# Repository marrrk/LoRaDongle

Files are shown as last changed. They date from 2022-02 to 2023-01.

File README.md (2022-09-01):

# LoRaDongle

LoRaDongle is a custom PCB that merges Risc-V with LoRa in a USB Dongle form factor. This repository contains all the project files required to build, utilise and modify the project. Documentation can be read from the site: [https://marrrk.github.io/LoRaDongle/](https://marrrk.github.io/LoRaDongle/)

## Cloning the repository

```bash
git clone --recurse-submodules https://github.com/marrrk/LoRaDongle.git
```

## Directory Structure

- PCB/ -  Contains the Kicad project files, schematics, gerbers, BOM and other PCB related files
- SOC/ - The python scripts that generate, build and load the Risc-V SoC onto the PCB
- firmware/ -  SUpporting firmware that runs on the SoC
- docs/ - Source files for the documentation website

**License** Licensed under [CERN-OHL-P v2](https://cern-ohl.web.cern.ch/) permissive variant or later.



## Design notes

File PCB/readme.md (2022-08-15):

# Overview
In order to open the Kicad project, open kicad and open the project file `LoRaDongle_iCE40.kicad_pro`. The schematic has been implemented with hierarchal sheets which allows the different submodules to be their own separate schematic. There are five total schematics for each module;
1. LoRaDongle_ice40.kicad_sch
2. power_management.kicad_sch
3. USB_Interface.kicad_sch
4. ice40up5k_sircuit.kicad_sch
5. sx1261_circuitry.kicad_sch

The other files and directories of relevance are:
- libraries/ - kicad symbols and footprints of specific components used
- manufacturing/  - gerbers, assembly files and images for manufacturing
- pdf_schematic/ - pdfs of the schematics of all versions
- silksceen/ - images that are converted into silkscreen footprints

# Contents of the Schematics
## LoRaDongle_ice40
The root schematic that is at the top of the heirarchy. Contains the connecting signals between various subsystems and other components such as the USB connector.

## power_management.kicad_sch
Contains the board's regulator. Steps down 5V to 3.3V and 1.2V.

## USB_Interface.kicad_sch
Houses the FTDI FT2232HL IC that converts the USB protocol into SPI for the FPGA configuration and UART for communicating with the SoC.

## ice40up5k_circuit.kicad_sch
This schematic holds the FPGA banks and related circuitry. This includes the SPI Flash, the oscillator, gas sensor and a header of all unused pins.

## sx1261_circuitry.kicad_sch
This is the RF section of the schematic. It contains the LoRa chip used (SX1261) and the supporting circuitry.

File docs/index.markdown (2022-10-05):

---
# Feel free to add content and custom Front Matter to this file.
# To modify the layout, see https://jekyllrb.com/docs/themes/#overriding-theme-defaults

layout: home
title: Home
nav_order: 1
---
## Introduction

LoRaDongle is a project that aims to merge the Open Source ISA Risc-V with the wireless modulation protocol LoRa.

Currently, the second prototype is in development in which various different tools and systems are brought together to build the project.
The project is executed on a custom PCB that is populated with a Low Power Lattice FPGA - the iCE40UP5k that houses a softcore SoC.  On the same board, a SX1261 LoRa transeiver is populated and configured to transmit at 868MHz.

The two prototypes and therefore design evolution are pictured below.
<div>
    LoRaDongle Versions
</div>

**License** Licensed under [CERN-OHL-P v2](https://cern-ohl.web.cern.ch/) or later.

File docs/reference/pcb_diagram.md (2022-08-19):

---
title: PCB
layout: page
parent: Reference Guide
nav_order: 2
---

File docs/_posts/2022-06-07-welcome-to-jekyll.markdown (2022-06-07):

---
layout: post
title:  "Welcome to Jekyll!"
date:   2022-06-07 11:42:06 +0200
categories: jekyll update
---
You’ll find this post in your `_posts` directory. Go ahead and edit it and re-build the site to see your changes. You can rebuild the site in many different ways, but the most common way is to run `jekyll serve`, which launches a web server and auto-regenerates your site when a file is updated.

Jekyll requires blog post files to be named according to the following format:

`YEAR-MONTH-DAY-title.MARKUP`

Where `YEAR` is a four-digit number, `MONTH` and `DAY` are both two-digit numbers, and `MARKUP` is the file extension representing the format used in the file. After that, include the necessary front matter. Take a look at the source for this post to get an idea about how it works.

Jekyll also offers powerful support for code snippets:

{% highlight ruby %}
def print_hi(name)
  puts "Hi, #{name}"
end
print_hi('Tom')
#=> prints 'Hi, Tom' to STDOUT.
{% endhighlight %}

Check out the [Jekyll docs][jekyll-docs] for more info on how to get the most out of Jekyll. File all bugs/feature requests at [Jekyll’s GitHub repo][jekyll-gh]. If you have questions, you can ask them on [Jekyll Talk][jekyll-talk].

[jekyll-docs]: https://jekyllrb.com/docs/home
[jekyll-gh]:   https://github.com/jekyll/jekyll
[jekyll-talk]: https://talk.jekyllrb.com/

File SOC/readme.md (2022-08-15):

# Introduction
This directory houses the SOC files. There exist the platform `Platform/LoRaDongle.py` and the target `LoRaDongle.py`. The platform describes the boards physical constraints while the target creates the SoC.

# Pre-requisites
The following tools need to be installed in order to succesfully generate and flash the SoC:
- LiteX
- Project IceStorm

# Building the SoC
Simply run the target script to generate the SoC.
```
$ python LoRaDongle.py --build
```

The script uses a vexriscv-lite as the default risc-v core. To change to the required core (Serv is the main core used in the project) run the following command:
```
$ python LoRaDongle.py --cpu-type serv --build
```

# Flashing the SoC
The same command can be run with the argument `--flash` to load the SoC onto the board.
```
$ python LoRaDongle.py --cpu-type serv --build --flash
```

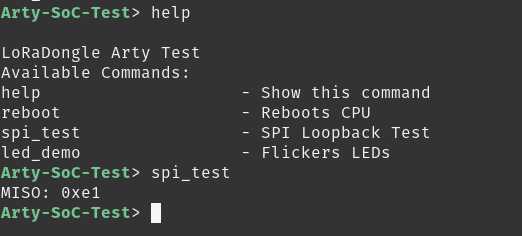
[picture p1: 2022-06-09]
docs/assets/images/soc_console_example.png

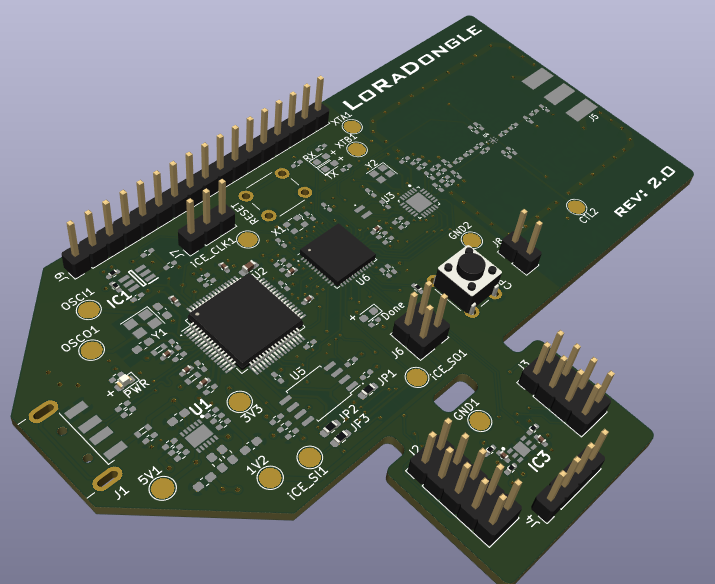
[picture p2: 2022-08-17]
docs/assets/images/LoRaDongle_V2.png

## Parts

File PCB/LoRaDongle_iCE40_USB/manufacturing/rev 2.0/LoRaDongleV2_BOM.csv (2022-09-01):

Item | Qty | Reference(s) | Value | Footprint | Description | Manufacturer | Manufacturer Part Number | Package | Type
1 | 12 | C1, C8, C9, C10, C12, C13, C16, C18, C19, C20, C21, C22 | 0.1uF | Capacitor_SMD:C_0402_1005Metric_Pad0.74x0.62mm_HandSolder | CAP CER 0.1UF 16V X7R 0402 | Murata Electronics | GCM155R71C104KA55J | 402 | SMD
2 | 3 | C2, C4, C6 | 10uF | Capacitor_SMD:C_0603_1608Metric_Pad1.08x0.95mm_HandSolder | CAP CER 10UF 6.3V X5R 0603 | Murata Electronics | GRM188R60J106ME47D | 603 | SMD
3 | 3 | C3, C5, C47 | 22pF | Capacitor_SMD:C_0402_1005Metric_Pad0.74x0.62mm_HandSolder | CAP CER 22PF 50V C0G/NP0 0402 | Murata Electronics | GRM1555C1H220FA01D | 402 | SMD
4 | 3 | C7, C11, C17 | 4.7uF | Capacitor_SMD:C_0402_1005Metric_Pad0.74x0.62mm_HandSolder | CAP CER 4.7UF 6.3V X6S 0402 | Murata Electronics | GRM155C80J475MEAAD | 402 | SMD
5 | 2 | C14, C15 | 27pF | Capacitor_SMD:C_0603_1608Metric_Pad1.08x0.95mm_HandSolder | CAP CER 27PF 50V C0G/NP0 0603 | Murata Electronics | GRM1885C1H270JA01D | 603 | SMD
6 | 11 | C23, C24, C25, C26, C27, C29, C30, C31, C32, C33, C57 | 100nF | Capacitor_SMD:C_0402_1005Metric_Pad0.74x0.62mm_HandSolder | CAP CER 0.1UF 16V X7R 0402 | Murata Electronics | GRM155R71C104KA88D | 402 | SMD
7 | 5 | C28, C34, C54, C55, C56 | 1uF | Capacitor_SMD:C_0402_1005Metric_Pad0.74x0.62mm_HandSolder | CAP CER 1UF 6.3V X7R 0402 | Murata Electronics | GRM155R70J105MA12D | 402 | SMD
8 | 1 | C35 | 10nF | Capacitor_SMD:C_0402_1005Metric_Pad0.74x0.62mm_HandSolder | CAP CER 10000PF 50V X7R 0402 | Murata Electronics | GRM155R71H103KA88J | 402 | SMD
9 | 2 | C36, C37 | 1.8pF | Capacitor_SMD:C_0402_1005Metric_Pad0.74x0.62mm_HandSolder | CAP CER 1.8PF 50V C0G/NP0 0402 | Murata Electronics | GRM1555C1H1R8WA01D | 402 | SMD
10 | 1 | C38 | 1pF | Capacitor_SMD:C_0402_1005Metric_Pad0.74x0.62mm_HandSolder | CAP CER 1PF 50V C0G/NP0 0402 | Murata Electronics | GRM1555C1H1R0BA01D | 402 | SMD
11 | 3 | C39, C40, C44 | 470pF | Capacitor_SMD:C_0402_1005Metric_Pad0.74x0.62mm_HandSolder | CAP CER 470PF 50V C0G/NP0 0402 | Murata Electronics | GRM1555C1H471JA01D | 402 | SMD
12 | 2 | C41, C43 | 33pF | Capacitor_SMD:C_0402_1005Metric_Pad0.74x0.62mm_HandSolder | CAP CER 33PF 50V C0G 0402 | TDK Corporation | CGA2B2C0G1H330J050BA | 402 | SMD
13 | 1 | C42 | 470nF | Capacitor_SMD:C_0402_1005Metric_Pad0.74x0.62mm_HandSolder | CAP CER 0.47UF 10V X5R 0402 | Murata Electronics | GRM155R61A474KE15D | 402 | SMD
14 | 1 | C45 | 47nF | Capacitor_SMD:C_0402_1005Metric_Pad0.74x0.62mm_HandSolder | CAP CER 0.047UF 16V X7R 0402 | Murata Electronics | GRM155R71C473KA01J | 402 | SMD
15 | 1 | C46 | 47pF | Capacitor_SMD:C_0402_1005Metric_Pad0.74x0.62mm_HandSolder | CAP CER 47PF 50V C0G/NP0 0402 | Murata Electronics | GRM1555C1H470JA01D | 402 | SMD
16 | 2 | C48, C50 | 3.3pF | Capacitor_SMD:C_0402_1005Metric_Pad0.74x0.62mm_HandSolder | CAP CER 3.3PF 50V C0G/NP0 0402 | Murata Electronics | GJM1555C1H3R3DB01D | 402 | SMD
17 | 1 | C49 | 3pF | Capacitor_SMD:C_0402_1005Metric_Pad0.74x0.62mm_HandSolder | CAP CER 3PF 50V C0G/NP0 0402 | Murata Electronics | GRM1555C1H3R0BA01J | 402 | SMD
18 | 1 | C51 | 6.8pF | Capacitor_SMD:C_0402_1005Metric_Pad0.74x0.62mm_HandSolder | CAP CER 6.8PF 50V C0G/NP0 0402 | Murata Electronics | GRM1555C1H6R8BA01D | 402 | SMD
19 | 1 | C52 | 12pF | Capacitor_SMD:C_0402_1005Metric_Pad0.74x0.62mm_HandSolder | CAP CER 12PF 50V C0G/NP0 0402 | Murata Electronics | GRM1555C1H120JA01J | 402 | SMD
20 | 1 | C53 | 3.3uF | Capacitor_SMD:C_0603_1608Metric_Pad1.08x0.95mm_HandSolder | CAP CER 3.3UF 10V X5R 0603 | Samsung Electro-Mechanics | CL10A335KP8NNNC | 603 | SMD
21 | 1 | D1 | PWR | LED_SMD:LED_0603_1608Metric | LED RED CLEAR SMD | Lite-On Inc. | LTST-C191KRKT | 603 | SMD
22 | 1 | D2 | Done | LED_SMD:LED_0603_1608Metric_Pad1.05x0.95mm_HandSolder | LED BLUE CLEAR CHIP SMD | SunLED | XZCBD53W-1 | 603 | SMD
23 | 1 | D3 | TX | LED_SMD:LED_0603_1608Metric_Pad1.05x0.95mm_HandSolder | LED GREEN CLEAR CHIP SMD | SunLED | XZVG53W-8 | 603 | SMD
24 | 1 | D4 | RX | LED_SMD:LED_0603_1608Metric_Pad1.05x0.95mm_HandSolder | LED GREEN CLEAR CHIP SMD | SunLED | XZVG53W-8 | 603 | SMD
25 | 3 | FB1, FB2, FB3 | 600R/0.5A | digikey-footprints:0603 | FERRITE BEAD 600 OHM 0603 1LN | Murata Electronics North America | BLM18AG601SN1D | 603 | SMD
26 | 1 | IC1 | 93LC56BT-I_OT | 93LC56B-I_OT_KiCad:SOT95P270X145-6N | 2K,128 X 16,Serial EE,SOT23 | Microchip | 93LC56BT-I/OT | SOT23-6 | SMD
27 | 1 | IC3 | SGP40-D-R4 | KiCad_SGP40-D-R4:SON80P244X244X95-7N | Air Quality Sensors Gas Sensor 2.5k pcs IC | Sensirion AG | SGP40-D-R4 | DFN | SMD
28 | 1 | J1 | USB_A | Connector_USB:USB_A_CNCTech_1001-011-01101_Horizontal | USB A 2.0, R/A, SMT, PLUG | Adam Tech | USB-AP-S-RA-SMT | Plug | SMD - Through Hole
29 | 1 | J2 | Conn_01x10_Male | Connector_PinHeader_2.54mm:PinHeader_2x05_P2.54mm_Vertical | 2x05 Male Header | - | - | - | Through HOle
30 | 1 | J3 | Conn_01x08_Male | Connector_PinHeader_2.54mm:PinHeader_2x04_P2.54mm_Vertical | 2x04 Male Header | - | - | - | Through Hole
31 | 1 | J4 | Conn_01x04_Male | Connector_PinHeader_2.54mm:PinHeader_1x04_P2.54mm_Vertical | 1x04 Male Header | - | - | - | Through Hole
32 | 1 | J5 | 142-0701-801 | digikey-footprints:RF_SMA_BoardEdge_142-0701-801 | CONN SMA JACK STR 50OHM EDGE MNT | Cinch Connectivity Solutions Johnson | 142-0701-801 | Connector | SMD
33 | 1 | J6 | Conn_02x02_Top_Bottom | Connector_PinHeader_2.54mm:PinHeader_2x02_P2.54mm_Vertical | 2x02 Male Header | - | - | - | Through hole
34 | 1 | J7 | Conn_01x03_Male | Connector_PinHeader_2.54mm:PinHeader_1x03_P2.54mm_Vertical | 1x03 Male Header | - | - | - | Through Hole
35 | 1 | J8 | Jumper_2_Open | Connector_PinHeader_2.54mm:PinHeader_1x02_P2.54mm_Vertical | 1x02 Male Header | - | - | - | Through Hole
36 | 1 | J9 | Conn_01x17_Male | Connector_PinHeader_2.54mm:PinHeader_1x17_P2.54mm_Vertical | 1x17 Male Header | - | - | - | Through Hole
37 | 3 | JP1, JP2, JP3 | SolderJumper_2_Open | Resistor_SMD:R_0603_1608Metric_Pad0.98x0.95mm_HandSolder | RES 0 OHM JUMPER 1/10W 0603 | Stackpole Electronics Inc | RMCF0603ZT0R00 | 603 | SMD
38 | 2 | L1, L2 | 2.2uH | Inductor_SMD:L_0603_1608Metric_Pad1.05x0.95mm_HandSolder | FIXED IND 2.2UH 1.2A 292MOHM SMD | Taiyo Yuden | MCHK1608T2R2MKN | 603 | SMD
39 | 2 | L3, L6 | 47nH | Inductor_SMD:L_0402_1005Metric_Pad0.77x0.64mm_HandSolder | FIXED IND 47NH 210MA 1.08OHM SMD | Murata Electronics | LQW15AN47NJ00D | 402 | SMD
40 | 1 | L4 | 18nH | Inductor_SMD:L_0402_1005Metric_Pad0.77x0.64mm_HandSolder | FIXED IND 18NH 370MA 270MOHM SMD | Murata Electronics | LQW15AN18NH00D | 402 | SMD
41 | 1 | L5 | 15uH | KiCad_VLS201610CX-150M-1:VLS2016 | FIXED IND 15UH 540MA 1.258OHM SM | TDK | VLS201610CX-150M-1 | 2016 | SMD
42 | 2 | L7, L9 | 9.1nH | Inductor_SMD:L_0402_1005Metric_Pad0.77x0.64mm_HandSolder | FIXED IND 9.1NH 540MA 140MOHM SM | Murata Electronics | LQW15AN9N1H00D | 402 | SMD
43 | 1 | L8 | 2.7nH | Inductor_SMD:L_0402_1005Metric_Pad0.77x0.64mm_HandSolder | FIXED IND 2.7NH 850MA 50MOHM SMD | Murata Electronics | LQW15AN2N7C00D | 402 | SMD
44 | 2 | R1, R2 | 10R | Resistor_SMD:R_0402_1005Metric_Pad0.72x0.64mm_HandSolder | RES 10 OHM 1% 1/16W 0402 | Stackpole Electronics Inc | RMCF0402FT10R0 | 402 | SMD
45 | 5 | R3, R18, R19, R20, R21 | 100R | Resistor_SMD:R_0402_1005Metric_Pad0.72x0.64mm_HandSolder | RES 100 OHM 1% 1/16W 0402 | Stackpole Electronics Inc | RMCF0402FT100R | 402 | SMD
46 | 1 | R4 | 453K | Resistor_SMD:R_0402_1005Metric_Pad0.72x0.64mm_HandSolder | RES 453K OHM 1% 1/16W 0402 | Stackpole Electronics Inc | RMCF0402FT453K | 402 | SMD
47 | 3 | R5, R6, R7 | 100K | Resistor_SMD:R_0402_1005Metric_Pad0.72x0.64mm_HandSolder | RES 100K OHM 5% 1/16W 0402 | Stackpole Electronics Inc | RMCF0402JT100K | 402 | SMD
48 | 1 | R8 | 1K | Resistor_SMD:R_0402_1005Metric_Pad0.72x0.64mm_HandSolder | RES 1K OHM 1% 1/16W 0402 | Stackpole Electronics Inc | RMCF0402FT1K00 | 402 | SMD
49 | 1 | R9 | 2K | Resistor_SMD:R_0402_1005Metric_Pad0.72x0.64mm_HandSolder | RES 2K OHM 1% 1/16W 0402 | Stackpole Electronics Inc | RMCF0402FT2K00 | 402 | SMD
50 | 11 | R10, R13, R14, R15, R16, R17, R22, R23, R24, R25, R27 | 10K | Resistor_SMD:R_0402_1005Metric_Pad0.72x0.64mm_HandSolder | RES 10K OHM 1% 1/16W 0402 | Stackpole Electronics Inc | RMCF0402FT10K0 | 402 | SMD
51 | 1 | R11 | 12K | Resistor_SMD:R_0402_1005Metric_Pad0.72x0.64mm_HandSolder | RES 12K OHM 1% 1/16W 0402 | Stackpole Electronics Inc | RMCF0402FT12K0 | 402 | SMD
52 | 1 | R12 | 2k2 | Resistor_SMD:R_0402_1005Metric_Pad0.72x0.64mm_HandSolder | RES 2.2K OHM 1% 1/16W 0402 | Yageo | RC0402FR-072K2L | 402 | SMD
53 | 1 | R26 | 4.7 | Resistor_SMD:R_0402_1005Metric_Pad0.72x0.64mm_HandSolder | RES 4.7 OHM 1% 1/16W 0402 | Stackpole Electronics Inc | RMCF0402FT4R70 | 402 | SMD
54 | 2 | SW1, SW2 | SW_Push | Button_Switch_THT:SW_PUSH_6mm_H5mm | 6 X 6 MM, 5.5 MM ACTUATOR HEIGHT | CUI Devices | TS02-66-55-BK-100-LCR-D | Through Hole | Through Hole
55 | 1 | U1 | RP550K001A-TR | RP550K001A-TR_KiCad:SON50P270X300X60-13N | BUCK DC/DC CONVERTER DUAL OUTPUT | Nisshinbo Micro Devices Inc. | RP550K001A-TR | DFN(PLP)2730-12 | SMD
56 | 1 | U2 | FT2232HL | Package_QFP:LQFP-64_10x10mm_P0.5mm | IC USB HS DUAL UART/FIFO 64-LQFP | FTDI, Future Technology Devices International Ltd | FT2232HL | 64-LQFP | SMD
57 | 1 | U3 | SX1261IMLTRT | sx1261-footprint:Semtech-QFN24-0-0-0 | TXRX LORA SUB-GHZ 15DBM 24MLPQ | Semtech | SX1261IMLTRT | QFN24 | SMD
58 | 1 | U4 | SKY13587-378LF | SW_SKYA21012:SW_SKYA21012 | IC RF SWITCH SPDT 6GHZ 6MLPD | Skyworks Solutions Inc. | SKY13587-378LF | 6-MLPD | SMD
59 | 1 | U5 | W25Q128JVS | Package_SO:SOIC-8_5.23x5.23mm_P1.27mm | IC FLASH 128MBIT SPI/QUAD 8SOIC | Winbond Electronics | W25Q128JVSIM TR | 8-SOIC | SMD
60 | 1 | U6 | ICE40UP5K-SG48I | Package_DFN_QFN:QFN-48-1EP_7x7mm_P0.5mm_EP5.6x5.6mm |  | Lattice Semiconductor | ICE40UP5K-SG48ITR50 | 48-QFN | SMD
61 | 1 | X1 | ECS-2520MV-500-BL-TR | Oscillator:Oscillator_SMD_ECS_2520MV-xxx-xx-4Pin_2.5x2.0mm | XTAL OSC XO 50.0000MHZ CMOS SMD | ECS Inc. | ECS-2520MV-500-BL-TR | 4 Pin Crystal | SMD
62 | 1 | Y1 | Crystal_GND24_Small | Crystal:Crystal_SMD_3225-4Pin_3.2x2.5mm | CRYSTAL 12.0000MHZ 18PF SMD | Abracon LLC | ABM8-12.000MHZ-B2-T | 4 Pin Crystal | SMD
63 | 1 | Y2 | Crystal_GND24 | Crystal:Crystal_SMD_2520-4Pin_2.5x2.0mm | CRYSTAL 32.0000MHZ 10PF SMD | ECS Inc. | ECS-320-10-36B-CKM-TR | 4 Pin Crystal | SMD

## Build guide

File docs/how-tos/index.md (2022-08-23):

---
title: How To Guides
layot: page
nav_order: 4
permalink: how-to/
has_children: true
---

This section provides various how-to guides on the board and its functionality.

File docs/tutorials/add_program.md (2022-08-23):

---
title: Write a Program - Blinky
layout: page
parent: Tutorials
nav_order: 3
---

# Introduction
The demo SoC application is a working implementation of a program running on the SoC. You would obviously want to write your own firmware to run, and so this section describes how to do just that. It focuses on the C code specifically, as the linker files are dependent on the SOC and it's assumed the SOC is unchanged.

# Setting up the working directory
The location of the source files are not imperative, the only important thing is to ensure the makefile is aware of where to get them. For this tutorial, we will create a subdirectory in the firmware directory; `mkdir blinky`. 

Copy the `ld` directory found in the demo application to your new directory. The file is the same as the SoC is unchanged. Next you'll need a `main.c` and a `Makefile` to store the code and toolchain. Your new directory should now look like this:
<div>
    Blinky Tree
</div>

# Writing C Code

## What register to write to
The LED we will be turning on is the RX LED located below header J9. Looking at the platform definition of the board, we see that the two LEDS are set up under the peripheral `user_leds` ;

```python
# Leds
("user_led", 0, Pins("E4"),  IOStandard("LVCMOS33")),           #RX LED
("user_led", 1, Pins("F4"),  IOStandard("LVCMOS33")),           #TX LED
```

The leds are then called into the SOC in the target script under the name `leds`. We can see we are using the `gpio` core that LiteX has in the source files. It hanled input pins, output pins and biderictional pins. As we are working with LEDs, the output class `GPIOOut()` is used.
```python
# Leds
user_leds = Cat(*[platform.request("user_led", i) for i in range(2)])
self.submodules.leds = gpio.GPIOOut(user_leds)
self.add_csr("leds")
```
LiteX then generates the necessary header file containing the macro functions to interact with the LED register. This is found in the `csr.h` as mentioned in the [Programming SoC](../getting-started/programming_SOC) page. The necessary section of the file is under the led section, and is shown below:

```c
/* leds */
#define CSR_LEDS_BASE (CSR_BASE + 0x0L)
#define CSR_LEDS_OUT_ADDR (CSR_BASE + 0x0L)
#define CSR_LEDS_OUT_SIZE 1
static inline uint32_t leds_out_read(void) {
	return csr_read_simple(CSR_BASE + 0x0L);
}
static inline void leds_out_write(uint32_t v) {
	csr_write_simple(v, CSR_BASE + 0x0L);
}
```
As you can see, the location in memory is created as macros and is used in simple functions `leds_out_read()` and `leds_out_write()`. To utilise them, they just need to be called in the source code.

## Writing main.c
Looking at the generated documentation, you find that the generated register has the two LSBs available to be written to. The combinations of values that can be written are `0b00`, `0b01`, `0b10` and `0b11`. Each bit corresponds to an LED pin it has been mapped to in the platform. So in this case, bit 0 corresponds to the RX LED and bit 1 corresponds to the TX LED.

<div>
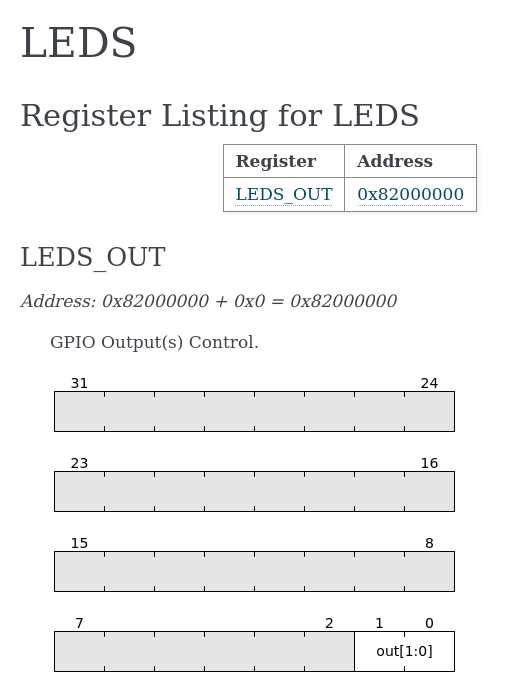
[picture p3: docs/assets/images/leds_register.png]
LED Documentation

</div>

Write the following code into `main.c`

```c
#include <generated/csr.h>

int main(void){
	leds_out_write(0x1);	
	return 0;
}
```

The program is very simple and simply writes a value of 1 to the CSR register, and turns on the LED. 

The code needs now needs to be compiled, and that involves writing the makefile. 

# Makefile
While the code so far is quite simple, setting up the toolchain via the proper structuring of the makefile is slighlty more complex. You need to tell the compiler certain things like where to find the source  and linker files, what flags to use and how to relate different outputs of the compilation process. To properly navigated the makefile, there are also variable names that are used, and most important of which is macros for the directories of important files. 

Using makefiles can become very complex and this section is a minimal introduction on how to make the most efficient version for the LoRaDongle. A more in depth tutorial on how to set up makefiles can be found easily online.

## Directory Variables
The first thing to include in the makefile is the required directories. The following code is used to do that:

```makefile
BUILD_DIR?=../../SOC/main/build/LoRaDongle

include $(BUILD_DIR)/software/include/generated/variables.mak
include $(SOC_DIRECTORY)/software/common.mak

BASE_DIR = .
OBJ_DIR = .obj
LD_DIR = $(BASE_DIR)/ld
```

`variables.mak` and `common.mak` are litex generated files that have even more macros that you would want to use in the compilation process. This includes the directory the SOC was built in, the directory of the CPU being used, the necessary flags to run the compiler for the chosen cpu, the compilation and linking flags and more. With these set up, you can move on to the next stage.

## Source files and flags
The makefile operates on specific file names as the dependency for a target. However, projects with many files would therefore need endless number of targets which would make the makefile long and repitive. So we want a way to go through chosen directories and generate a list of files. This is done with the `wildcard` function, and is implemented in the following way:

```makefile
CSOURCES   := $(wildcard *.c) 
ASOURCES   := $(wildcard $(CPU_DIRECTORY)/crt0.S)
```

This way, the variable `CSOURCES` will contain a list of files that all contain the ending `.c` and the same can be said about `ASOURCES`. While we are here, let's also create a variable for where the object files will be stored:

```makefile
COBJS      := $(addprefix $(OBJ_DIR)/, $(notdir $(CSOURCES:.c=.o)))
AOBJS      := $(addprefix $(OBJ_DIR)/, $(notdir $(ASOURCES:.S=.o)))
OBJECTS = $(COBJS) $(AOBJS)
```

Now, you can add more c files in the blinky directory and would not need to add targets to the makefile. We will add more to this section later when we are trying to blink the led. 
Something else that will come into effect later is updating the flags to include directories to search for header files. To set that infrastructure up, we are going to add the following lines to the makefile:

```makefile
c_flags =  $(CFLAGS)
l_flags = $(LDFLAGS)

define compile
$(CC) -c $(c_flags) $(1) $< -o $@
endef
```

## Targets
Here, the whole compilation process is broken down to get the compiler to do exactly what we want. This is espeically important when it comes to the linking step, which is where the linker script found in `ld/` is included. The following code is used to compile the targets, assemble the assembly code and finally link the object files into a single executable.

```makefile
$(OBJECTS): | $(OBJ_DIR)

$(OBJ_DIR):
	@mkdir $(OBJ_DIR)

# pull in dependency info for *existing* .o files
-include $(OBJECTS:.o=.d)

%.bin: %.elf
	$(OBJCOPY) -O binary $< $@
	chmod -x $@

blinky.elf: $(OBJECTS)
	$(CC) $(l_flags) \
		-T $(LD_DIR)/linker.ld \
		-N -o $@ \
		$(OBJECTS) \
		$(PACKAGES:%=-L$(BUILD_DIR)/software/%) \
		$(LIBS:lib%=-l%)
	chmod -x $@

$(OBJ_DIR)/main.o: main.c
	$(compile)

$(OBJ_DIR)/crt0.o: $(CPU_DIRECTORY)/crt0.S
	$(assemble)

%.o: %.S
	$(assemble)

```

As you can see, the targets all have dependencies, and in some cases the dependencies are other targets. This creates a step by step process in the compilation. A simplified version of this is as follows:
1. Compile the .c source files to object files
2. Assemble the .s source files to object files
3. Link the object files to create the .elf file
4. Change the file format to a .bin. 

### Programming board and cleaning up
Ypu can also create a target that runs the bash command to load the executable file into the SPIFlash of the SOC. This is so that you don't have to remember the command to run as it's much easier to run `make prog`:

```makefile
prog: blinky.bin
	iceprog -o 0x00020000 $<
```

You would also want a way to delete all the generated files and 'clean up' any generated files. And lastly, it's good practice to tell make which dependcies are not actually files that already exist in the directory. This is done in the following lines:

```makefile
clean:
	$(RM) $(OBJECTS) $(OBJECTS:.o=.d) blinky.elf blinky.bin .*~ *~
	$(RM) -r $(OBJ_DIR)

.PHONY: all $(OBJ_DIR)/main.o clean run
```

# Final Makefile
WIth all key sections in the makefile now, your makefile should look like this:

```makefile
BUILD_DIR?=../../SOC/main/build/LoRaDongle

include $(BUILD_DIR)/software/include/generated/variables.mak
include $(SOC_DIRECTORY)/software/common.mak

BASE_DIR = .
OBJ_DIR = .obj
LD_DIR = $(BASE_DIR)/ld

CSOURCES   := $(wildcard *.c) 
ASOURCES   := $(wildcard $(CPU_DIRECTORY)/crt0.S)
COBJS      := $(addprefix $(OBJ_DIR)/, $(notdir $(CSOURCES:.c=.o)))
AOBJS      := $(addprefix $(OBJ_DIR)/, $(notdir $(ASOURCES:.S=.o)))

OBJECTS = $(COBJS) $(AOBJS)

c_flags =  $(CFLAGS)
l_flags = $(LDFLAGS)

define compile
$(CC) -c $(c_flags) $(1) $< -o $@
endef

all: blinky.bin

$(OBJECTS): | $(OBJ_DIR)

$(OBJ_DIR):
	@mkdir $(OBJ_DIR)

# pull in dependency info for *existing* .o files
-include $(OBJECTS:.o=.d)

%.bin: %.elf
	$(OBJCOPY) -O binary $< $@
	chmod -x $@

blinky.elf: $(OBJECTS)
	$(CC) $(l_flags) \
		-T $(LD_DIR)/linker.ld \
		-N -o $@ \
		$(OBJECTS) \
		$(PACKAGES:%=-L$(BUILD_DIR)/software/%) \
		$(LIBS:lib%=-l%)
	chmod -x $@

$(OBJ_DIR)/main.o: main.c
	$(compile)

$(OBJ_DIR)/crt0.o: $(CPU_DIRECTORY)/crt0.S
	$(assemble)

%.o: %.S
	$(assemble)

prog: blinky.bin
	iceprog -o 0x00020000 $<

clean:
	$(RM) $(OBJECTS) $(OBJECTS:.o=.d) blinky.elf blinky.bin .*~ *~
	$(RM) -r $(OBJ_DIR)

.PHONY: all $(OBJ_DIR)/main.o clean run
```

Go ahead and run `make` to compile the earlier program, and then `make prog` to load it onto the board. If successful, you should see the RX LED turn on!

# Adding peripherals to make the LED blink
Naturally, now we would like the LED to blink on and off. To do this we would need to incorporate timers that set the frequency of the blink. A timer peripheral is set up automatically with all SOCs, so that is what we're going to use. 

## Getting the timer peripheral source files
Make a new directory in `blinky/` and name it peripherals and copy `timer.h` and `timer.c` from  `demo/peripherals` into your new directory. The structure should look like:

<div>
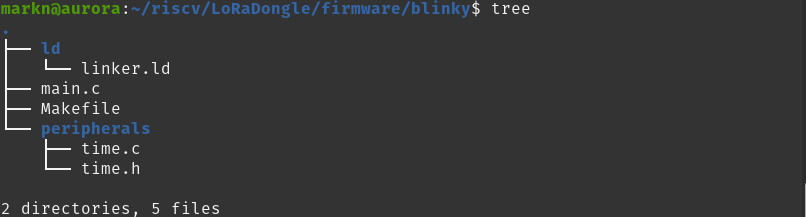
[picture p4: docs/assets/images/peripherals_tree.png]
Peripherals
    
</div>

## Updating main.c
There are two functions that utilise the timer as a counter. We will use `elapsed()` for this. Update `main.c` so that it has the following code:

```c
#include <generated/csr.h>
#include <time.h>

int main(void){
	time_init();
	int last_event = 0;
	int led_value;
	while (1) {
		//Flash LED every half a second
		if (elapsed(&last_event, (CONFIG_CLOCK_FREQUENCY * 0.5))){
			led_value = leds_out_read();
			leds_out_write(led_value ^ 1);
			}
	}
	return 0;
}
```

## Updating the makefile
Each section barre the last one needs to be updated, this is mostly because a new directory has been created. 

### Adding peripheral directory
In the section where you declare directory variables, add the following:
```makefile
PERIPHERAL_DIR = $(BASE_DIR)/peripherals
```

### Updating source files and flags
Using the `wildcard` function, update `CSOURCES` to contain files that come from `peripherals/`:
```makefile
CSOURCES   := $(wildcard *.c) $(wildcard $(PERIPHERAL_DIR)/*.c)
```

You also want to update the flags to include the header files in `peripherals/`. If you don't do this, the compiler won't know where the corresponding header files for the soruce files are found. 

```makefile
LOCAL_INCLUDE = -I$(PERIPHERAL_DIR)
L_INCLUDE = -L$(PERIPHERAL_DIR)

c_flags = $(LOCAL_INCLUDE) $(CFLAGS)
l_flags = $(L_INCLUDE) $(LOCAL_INCLUDE) $(LDFLAGS)
```

### Adding a new target
The last change to the makefile is to add a new target that sources the c files from the peripheral directory and compiles them to the object files. This is done just like it was with `main.c`. 

```makefile
$(OBJ_DIR)/%.o: $(PERIPHERAL_DIR)/%.c 
	$(compile)
```

With the final change done, you can run `make` and `make prog` again to load the new program. If successful, you should see the RX Led blinking!

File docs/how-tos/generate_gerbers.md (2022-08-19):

---
title: Generate Gerbers & Pick and Place Files
layout: page
parent: How To Guides
nav_order: 2
---
# Introduction
PCB Manufacturers have slightly differing options in how they receive gerber and assembly files. They usually provide a help section  on their websites that tells users how to generate files to work with their systems for a host of different schematic and PCB programs. As this project was built with KiCad and ordered from PCBWay, we will go through an example generating the files from KiCad for a PCBWay order.

# 1. Find Fabrication House Parameters
A quick google search should lead to PCBWay's instruction on generating gerber files from kicad. That leads to the webpage [Generate Gerber file from Kicad](https://www.pcbway.com/helpcenter/technical_support/Generate_Gerber_file_from_Kicad.html), which is a step-by-step instruction on generating the files on KiCad. Unfortunately however, the instructions are for an older version of KiCad and the current version has differing names/options to select, but you can still generate the same files.

In adition to the gerbers, the centroid (pick and place) file for assembly also needs to be created. You find the instructions the same way, and [this](https://www.pcbway.com/helpcenter/technical_support/Generate_Position_File_in_Kicad.html) is the PCBWay instruction webpage.

# 2. Generating Gerbers and Drill Files on KiCad 6

## 2.2 Generating Gerbers
The steps on the pcbway page are the same, open `File -> Plot` and you will be greeted with the plot screen. The following image is the settings that PCBWay requires, but on Kicad 6:
<div>
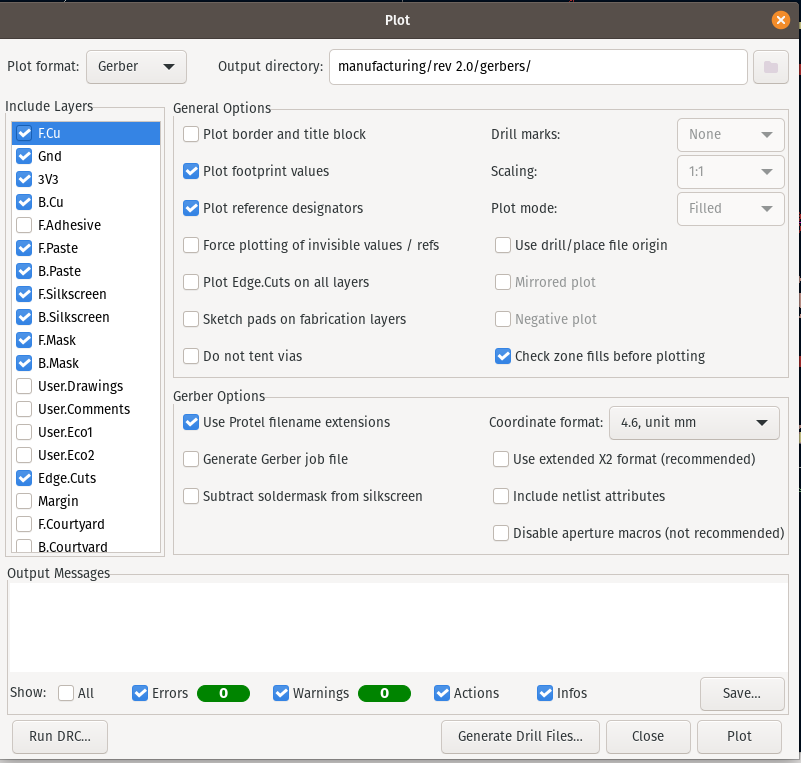
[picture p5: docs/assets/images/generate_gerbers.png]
    
</div>

Once satisfied with the settings, click on plot and the files will be generated and placed in the directory of your choice.

## 2.2 Generating Drill Files
With the gerbers generated, click on generate drill files. The settings that need to be selected are shown in the image below.

<div>
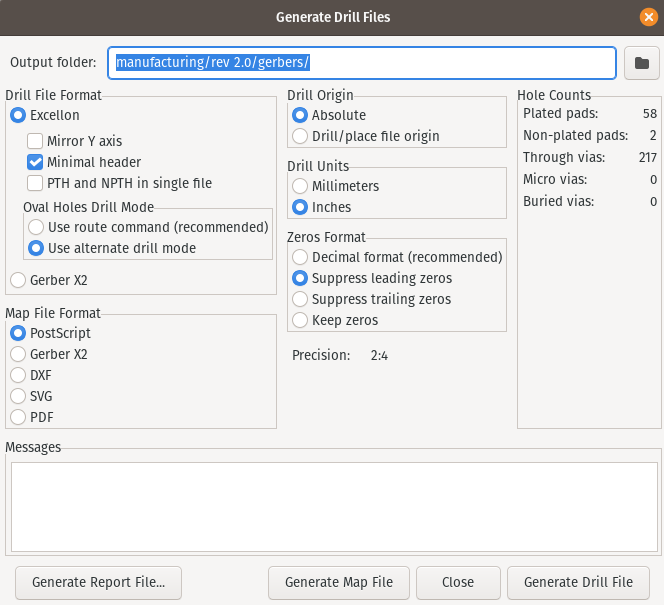
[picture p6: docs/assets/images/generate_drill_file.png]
    
</div>

Once satisfied, click on generate drill file.

# 3. Generating Centroid File on KiCad 6
The origin point should already be set in the project. However if not, you can set it the same way as PCBWay instruct.
To open the placement file wizard, navigate to `File -> Component Placement (.pos)`. The following image shows the settings that must be selected.

<div>
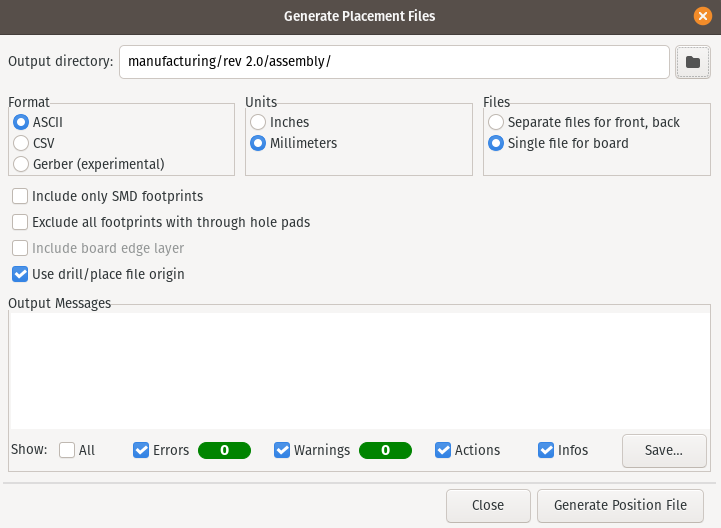
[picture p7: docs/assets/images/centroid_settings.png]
    
</div>

Click on Generate Promote File.

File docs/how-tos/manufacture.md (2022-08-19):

---
title: Manufacture Board
layout: page
parent: How To Guides
nav_order: 1
---

# Introduction
The PCB manufacturer that was used to fabricate the prototype was [PCBWay](https://www.pcbway.com/). You are not strictly confined to use this manufacturer and can generate the required files to match one of your choice. However if you choose this manufacturer, the files are already generated in the correct format. These can be found in `PCB/LoRaDongle_iCE40_USB/manufacturing/rev 2.0`. The LoRaDongle BOM is also found in this directory. 

Choosing a different manufacturer may also require changing the track sizes of the RF section so as to impedance match to 50<span>&#8486;</span>. This is due to the different stackup that would be used.

# 1. Ordering from PCBWay
NB: The following instructions are for the already generated gerber files. To generate your own for a different manufcaturer, please look at [Generating Gerbers for a different fabrication house](generate_gerbers).

## 1.1 Inputting PCB Parameters
Go to the PCBWay website. On the top of homepage of the website there is an instant prototype quote section. Input the PCB parameters (67mm x 95mm, 4 layers, 1.6mm thicnkess) and click quote now. You will be taken to a quote page where you are given a price for the information you put. You may need to name the layers before being taken to the quote page. The names are as follows:

<div>
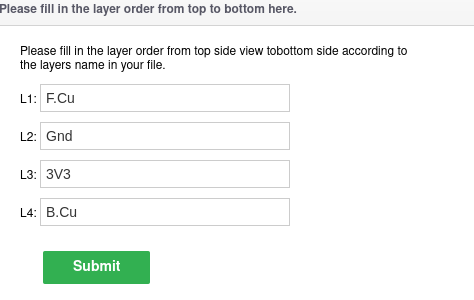
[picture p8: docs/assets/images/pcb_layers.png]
PCB Layers
    
</div>

Once on the order online/quote page, you are greeted with more options to order. The image below shows the settings required to be chosen when ordering from PCBWay. They pertain to the PCB characteristics and therefore should be applicable to most manufactures. 
<div>
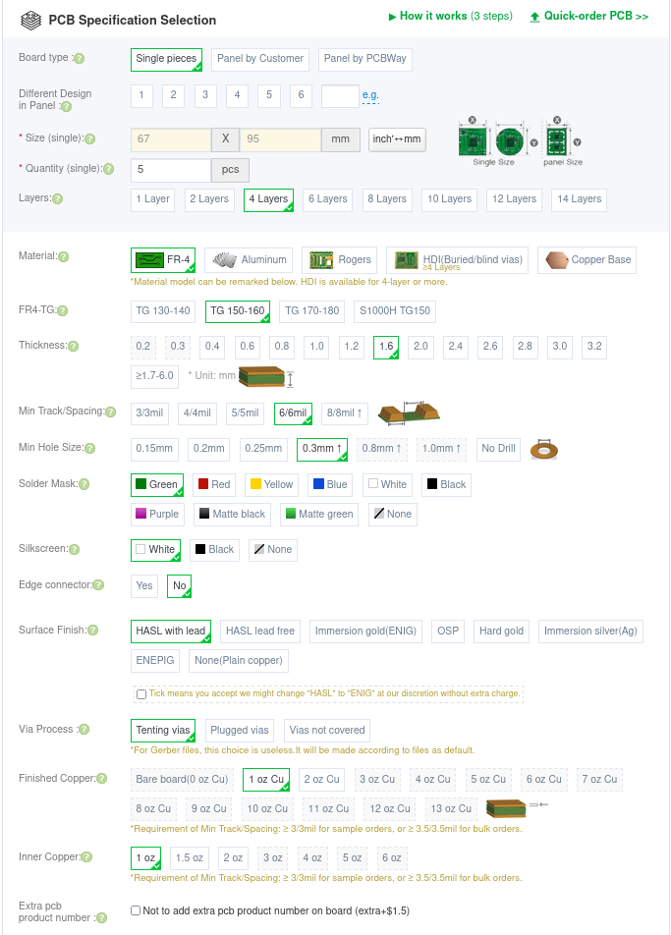
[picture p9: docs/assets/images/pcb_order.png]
PCB Order Details
    
</div>

The important parameters to input are the baord size and number of layers, and pcb thickness. Changing the thickness alters the stackup which could affect the efficiency of the RF section of the board.

## 1.2 Assembly Options
Afther the PCB parameters section, there should be an assembly service checkbox that is automatically deselected. Select it to request assembly.

The image below shows the required input options for LoRaDongle. The turnkey service is used to source the parts on the board, with parts not already in stock ordered from reputable sources (digikey, mouser, etc). To do this, the BOM is also submitted with the pick and place file. PCBWay will be in contact with a quote and information about the components in stock or not.

<div>
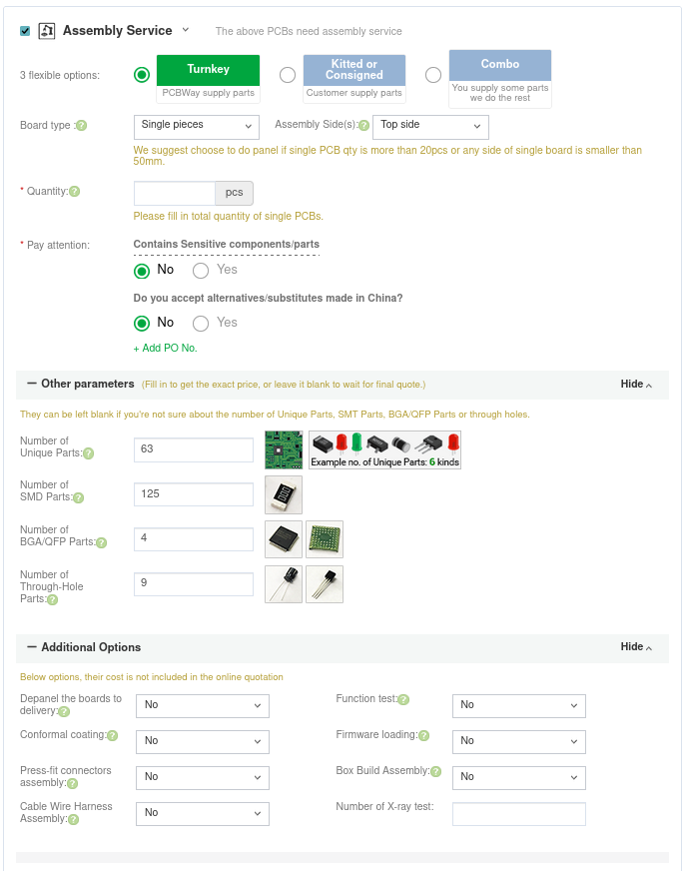
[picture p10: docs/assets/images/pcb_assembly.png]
PCB Assembly
    
</div>

## 1.3 Submitting order and Uploading files
Once the PCB specification and assembly service sections have been filled, click calculate to get the quote. You would also be required to choose the shipping destination and preferred courier. These choices will also affect final price. 

Once satisfied, click add to card and your order will be sent to PCBWAy. However this is not complete, it is now you will be prompted to upload the necessary files. As mentioned in the introduction, these are found in `PCB/LoRaDongle_iCE40_USB/manufacturing/rev 2.0`. The files you need to upload are:
* LoRaDongleV2_BOM.csv
* gerbers/LoRaDongle_V2.zip
* assembly/LoRaDongle_iCE40-all.pos
* assembly/LoRaDongleV2_pdfs.zip

The assembly PDFs are not necessary but help the PCBWay engineers in insuring the assembly process is in line with your designs.

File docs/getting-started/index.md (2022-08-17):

---
title: Getting Started
layot: page
nav_order: 2
permalink: getting-started/
has_children: true
---
# Getting Started
The goal of this section is to build up to a working program on the SoC. The necessary links and steps to get to that will be shown here.

## Prerequisites

### Hardware
The current supported boards are the LoRaDongle which has the Lattice ICE40UP5k and the Arty A7 development board by Xilinx which has the Artix-7 100T.
To use the Arty A7, you would need to clone the `test/arty` branch of the repository.

### Software
* [LiteX](https://github.com/enjoy-digital/litex)
* Risc-v GCC Toolchain - Which can be installed with LiteX
* The necessary synthesis and routing software for the FPGA in use. For the LoRaDongle (and other Lattice FPGAs), this is [Project Icestorm](https://clifford.at/icestorm). For Digilent boards, this is [Vivado](https://www.xilinx.com/support/download.html).

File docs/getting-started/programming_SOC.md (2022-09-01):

---
layout: page
title: Programming SoC
parent: Getting Started
nav_order: 4
---

## Generated Files

The softwate build directory contains a subdirectory `software/include/generated` that stores core files for the successful programming of the SOC. This includes linker scripts, makefile extensions and crucial header files.

Specifically, important linker information is found in `output_format.ld` and `regions.ld`. These would need to be included in the linker script of your application such that the correct memory locations are utilised. `variables.mak` stores useful macros for use in the makefile of your application.

Every peripheral in the SoC is controlled via memory mapped registers called CSRs. In order to interact with the peripherals, the specific registers in memory need to be written to.

For example, including GPIO pins in the SOC creates a CSR register that needs to be written to or read from in order to set or read the status of the corresponing pins Thankfully, part of the generated files from building the SOC contains all the CSR addresses as well as functions that handle writing and reading from the peripherals. The file that contains all these functions is`csr.h`.

The included makefile in the `firmware` directory is configured to look into this folder for the necessary files during the compilation process.

## Building and running the Test Program - LoRaDongle Demo Test

### File Structure

Navigate to the `firmware` directory in the project, the current file structure is shown in the image below:
<div>
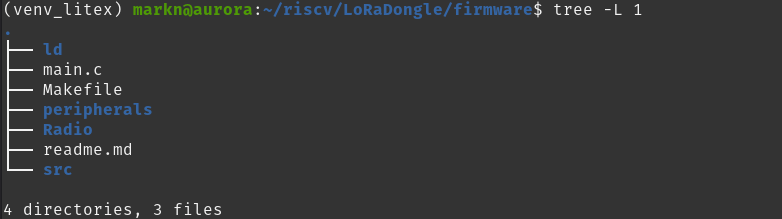
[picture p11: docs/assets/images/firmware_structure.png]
File Structure
    
</div>

The purpose of the subdirectories is as follows:

* `ld/` - Contains the main linker script to link binaries together
* `peripherals/` - Code and drivers that interact with the peripherals of the system.
* `Radio/` - Driver code for the LoRa radio

The makefile reads all the source and linker files from these directories, in addition to assembly start up code found in the LiteX install and `main.c`. To create the executable, run the makefile command `make`. The compilation results in the binary file `demo.bin` that can be loaded onto LoRaDongle's SPI Flash at a specific memory address that the CPU reads from to execute the program. This is done with the command `make prog`. 

The successful ouput of that is shown below:
<div>
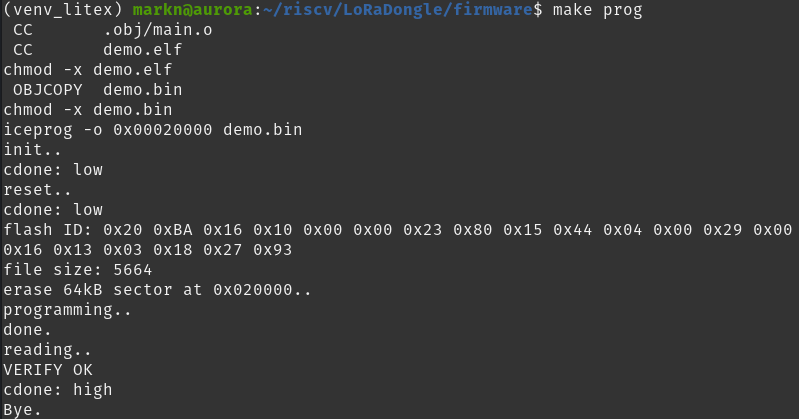
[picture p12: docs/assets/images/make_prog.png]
make prog
    
</div>

If successful, the two green LEDS on the board should flicker for about 3 seconds.

You can then opena  serial terminal to interact with the SOC. The baudrate needs to be set to 115200, for example `screen /dev/ttyUSB0 115200`. This is the prompt you should see when you open the serial terminal:
<div>
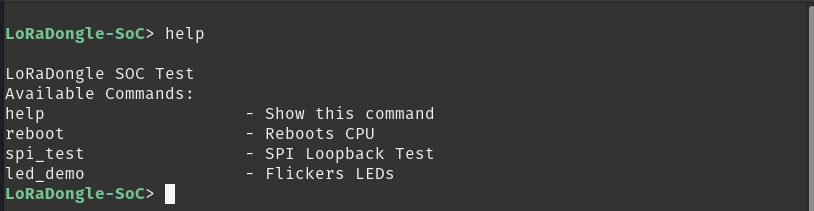
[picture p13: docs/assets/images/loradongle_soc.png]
Serial Terminal
    
</div>

## Building and running the Test Program - Arty Demo Test

Navigate to `LoRaDongle/SOC/arty_test/firmware` and run `make`. This will create binary file titled `demo.bin` to be loaded to the SoC. Hopefully everything built successfully with no errors. 

Then call `make run` to load the application code to the SoC. You should see the LiteX bios starting and then loading the application code onto the SoC. See below:

<div>
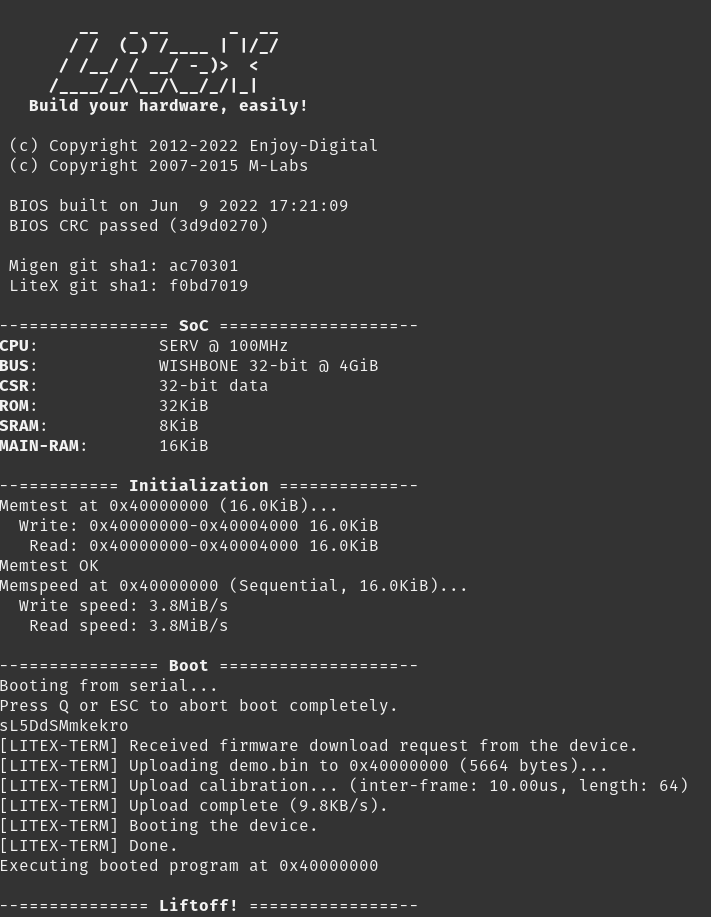
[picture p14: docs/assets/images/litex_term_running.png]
LiteX Term
    
</div>

Once loaded you will be greeted with the pompt `Arty-SoC-Test>` in which you can run the two to three functions that have been implemented. See below

If however you did not get this, try pressing the cpu reset button on the development you are using to reboot the SoC.

## Adding your own program

Additional source files can be added to the program. You can place them in the `peripherals/` directory directly. ALternatively, you can create your own bespoke directory for the funcionality being added.

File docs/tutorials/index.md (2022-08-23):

---
title: Tutorials
layot: page
nav_order: 3
permalink: tutorials/
has_children: true
---

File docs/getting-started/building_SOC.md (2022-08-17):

---
title: Building the SOC for test
layout: page
parent: Getting Started
nav_order: 3
---

# Building the SOC and Loading the SOC
## Cloning the Repository
The first step is to clone the repository found at [https://github.com/marrrk/LoRaDongle](https://github.com/marrrk/LoRaDongle). This can be done as usual, however if you want to view the kicad project for the schematic and PCB layout, clone the submodules as well via the command `git clone --recurse-submodules https://github.com/marrrk/LoRaDongle.git`. This clones the relevant libraries that some of the symbols and footprints are sourced from.

From henceforth, every path described will be from the root of the LoRaDongle directory. 

## Lattice FPGA
Navigate to the SOC directory, `SOC/main` to find the two python scripts required to successfully build the SOC:

build scripts

* The platform(`Platform/LoRaDongle.py`) that contains the physical represantion of the board and it's peripherals.
* The target(`LoRaDongle.py`) that contains the code that generates the SOC. 

### Generating and Loading the Bitstream
If the prerequisites have been installed correctly, running the target script with the necessary arguments will lead to the SOC being successfully built and loaded onto the board. This can be done with the command:
```
python LoRaDongle.py --cpu-type serv --build --flash
```
Once the script has been run, a new directory is created that contains the generated gateware and software. Both are necessary to sucessfully run a program on the SoC. The `gateware` directory contains the generated bitstream to be loaded onto LoRaDongle while the `software` directory contains the bios and various peripherals and header files that are used in writing a program for the SOC.

The iCE40UP5k has minimal logic slices and so the SoC is designed with the ROM region located in the external SPIFlash. For this region, the LiteX bios is not loaded into memory and rather we tell the CPU where to jump to start reading the application program. Therefore, in order to see if it was successful, we need to load the program into the SoC. See [Programming SoC](programming_SOC) for more details.

## Xilinx FPGA
### Generating Bitsream
Building the SOC is as simple as running a single script. It is important to make sure the environment is set up properly for the successful completion of the script. Two Things that may need to be setup prior to running are:
* The Litex Virtual environment is being used.
* The command `vivado` is in the path. You can do this by calling: `$ source /PATH_TO_VIVADO_INSTALL/VERSION_NUMBER/settings64.sh`

If the environment is setup correcly, navigate to `LoRaDongle/arty_test`. The SOC can be built using `python arty.py`.

This will take a few minutes to run, and if successful, the generated bitstream will be loaded to: `LoRaDongle/SOC/arty_test/build/gateware/top.bit`.

### Loading Bitstream
To load the bitstream, no shortcut way has been implemented as of yet. As such you need to manually run vivado and load the bitsream via the Graphical User Interface is done. The following steps are followed:
1. Open Vivado
2. Open Dummy Project (any project can be used, even an example project)
3. Connect Digilent Board to computer
4. Open Hardware Manager (on the bottom left of the screen)
5. Click Open target and then auto connect. 
6. Click Program Device
7. Look for the location that `top.bit` was generated for your SOC
8. Click Program

The SOC will then be loaded into the FPGA.

You can test it out by calling:
```bash
$ litex_term /dev/ttyUSB1
```
This will launch the liteX bios on the fpga, and you will be able to see some information about the SoC generated.

## Generating Documentation
The python script to build the SoCs also generate html documentation for the various cores, peripherals, memory regions and registers. the [LiteX Wiki](https://github.com/enjoy-digital/litex/wiki/SoC-Documentation) outlines what python modules need to be installed with `pip` in order to generate the documentation.

To generate the documentation, run the following command:

```bash
sphinx-build -M html build/documentation/ build/documentation/_build
```

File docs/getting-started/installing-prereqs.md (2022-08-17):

---
layout: default
title: Installing Prerequisites
parent: Getting Started
nav_order: 2
---

# Installing prerequisites

## 1 Installing LiteX and Toolchain
This section focuses on the core configuration required to build the SoC in use. A more comprehensive walkthrough of the installation process can be found on LiteX's [github page](https://github.com/enjoy-digital/litex).

### 1.1 Make an empty directory and install the Litex files
The following commands install litex in a directory of your choice:
```bash
$ mkdir litex && cd litex
$ wget https://raw.githubusercontent.com/enjoy-digital/litex/master/litex_setup.py
$ chmod +x litex_setup.py
$ ./litex_setup.py --init --install
```
If you wish to install to your user directory, you can call `$ ./litex_setup.py --init --install --user` instead.

Installing to a virtual environment is also possible:
```bash
$ mkdir litex && cd litex
$ virtualenv -p python3 venv_litex
$ source venv_litex/bin/activate 
$ wget https://raw.githubusercontent.com/enjoy-digital/litex/master/litex_setup.py
$ chmod +x litex_setup.py
$ ./litex_setup.py --init --install
```

### 1.2 Installing Toolchain
The Risc-V toolchain can also be installed with Litex. To do that simply call:
```bash
$ pip3 install meson ninja
$ ./litex_setup.py --gcc=riscv
```
The toolchain will be installed to a subdirectory in the litex directory and will be titled `riscv64-unknown-elf-gcc-8.3.0-2019.08.0-x86_64-linux-ubuntu14`

To enable the toolchain, add it to your path: 
```bash
$ export PATH="/PATH_TO_INSTALLATION/riscv64-unknown-elf-gcc-8.3.0-2019.08.0-x86_64-linux-ubuntu14/bin/:$PATH"
$ source .bashrc
```
Note the command above only adds the toolchain to the path for the current terminal session. In order add the toolcahin to the path permanently, append the same line to `.bashrc`.

## 2. Installing Synthesis Tools

### 2.1 Installing project Icestorm (Lattice FPGA)
Lattice Semiconductors have their own propiertary software for synthesising and configuring their FPGAS, however there are also open source tools that can be used. [Project Icestorm](https://clifford.at/icestorm) is a mature and well doucumented open source tool that is used. Installiation steps can be found on the website linked, and a summary of the necessary steps is given here. The tools needed are Yosys, Arachne-PNR and Icestorm. Once installed, you can look at a nice and concise guide on using the tools, found [here](https://hedmen.org/icestorm-doc/icestorm.html).

### 2.1.1 Intalling Icestorm
The repository needs to be cloned and installed: 

```bash
$ git clone https://github.com/YosysHQ/icestorm.git icestorm
$ cd icestorm
$ make -j$(nproc)
$ sudo make install
```
### 2.1.2 Installing NEXT-PNR

```bash
$ git clone https://github.com/YosysHQ/nextpnr nextpnr
$ cd nextpnr
$ cmake -DARCH=ice40 -DCMAKE_INSTALL_PREFIX=/usr/local .
$ make -j$(nproc)
$ sudo make install
```

### 2.1.3 Installing Yosys
```bash
$ git clone https://github.com/YosysHQ/yosys.git yosys
$ cd yosys
$ make -j$(nproc)
$ sudo make install
```

### 2.1.4 Creating UDEV Rules
On Linux machines, if you have an error configuring the fpga, you'd need to create the udev rules to allow your user account to connect to the development board using `iceprog`. In order to do that, 
run the following commands:
```bash
$ touch /etc/udev/rules.d/53-lattice-ftdi.rules
$ sudo nano /etc/udev/rules.d/53-lattice-ftdi.rules
```
When inside the file, add the following text:
```
ATTRS{idVendor}=="0403", ATTRS{idProduct}=="6010", MODE="0660", GROUP="plugdev", TAG+="uaccess"
```

### 2.1 Installing Vivado (Xilinx FPGA)
Vivado is a large download and may take hours on slow/unreliable internet connections. The download process can be found [here](https://digilent.com/reference/vivado/installing-vivado/v2019.2). The latest version can be installed, however _**please note this project has only been tested with version 2021.2**_.

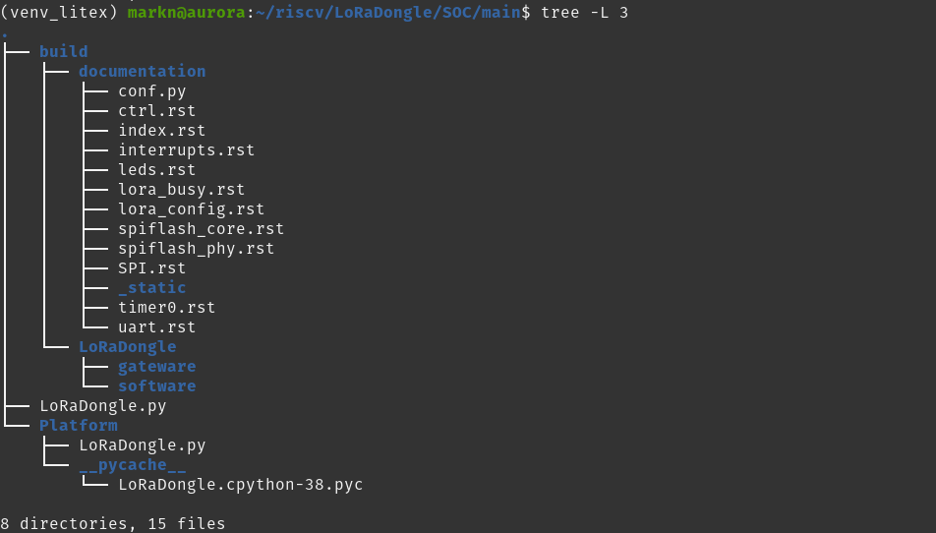
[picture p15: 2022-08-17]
docs/assets/images/build_dir.png

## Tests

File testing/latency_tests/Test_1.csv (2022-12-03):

Success | Time to Send | Time to Receive | Message Size | RSSI | RSSI Despread | SNR
True | 548.9447142857142 | 1195.2950952380952 | 4 | 0.0 | -0.5 | 3.25
True | 548.9447142857142 | 1193.0802380952382 | 4 | -0.5 | -0.5 | 3.0
True | 548.9447142857142 | 1195.2950952380952 | 4 | -0.5 | -0.5 | 3.0
True | 548.9447142857142 | 1193.0802380952382 | 4 | -0.5 | -0.5 | 3.0
True | 548.9447142857142 | 1195.2950952380952 | 4 | -0.5 | -0.5 | 3.0
True | 548.9447142857142 | 1193.0802380952382 | 4 | -0.5 | -0.5 | 3.0
True | 548.9447142857142 | 1195.2950952380952 | 4 | -0.5 | -0.5 | 3.0
True | 548.9447142857142 | 1193.0802380952382 | 4 | -0.5 | -0.5 | 3.0
True | 548.9447142857142 | 1195.2950952380952 | 4 | -0.5 | -0.5 | 3.0
True | 548.9447142857142 | 1193.0802380952382 | 4 | -0.5 | -0.5 | 3.0
True | 548.9447142857142 | 1195.2950952380952 | 4 | -0.5 | -0.5 | 3.0
True | 548.9447142857142 | 1193.0802380952382 | 4 | -0.5 | -0.5 | 3.0
True | 548.9447142857142 | 1195.2950952380952 | 4 | -0.5 | -0.5 | 3.0
True | 548.9447142857142 | 1193.0802380952382 | 4 | -0.5 | -0.5 | 3.0
True | 548.9447142857142 | 1195.2950952380952 | 4 | -0.5 | -0.5 | 3.0
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

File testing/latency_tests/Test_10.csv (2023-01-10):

Success | Time to Send | Time to Receive | Message Size | RSSI | RSSI Despread | SNR | Timestamp
True | 2777.884761904762 | 5693.387428571428 | 15 | -1.0 | -2.0 | 1.25 | 17:28:30
True | 2777.884761904762 | 5693.387428571428 | 15 | -1.0 | -2.0 | 1.25 | 17:28:40
True | 2777.884761904762 | 5693.387428571428 | 15 | -1.0 | -1.5 | 1.25 | 17:28:50
True | 2777.884761904762 | 5693.387428571428 | 15 | -1.0 | -1.5 | 1.75 | 17:29:00
True | 2777.884761904762 | 5693.387428571428 | 15 | -1.0 | -2.0 | 1.0 | 17:29:10
True | 2777.884761904762 | 5693.387428571428 | 15 | -1.0 | -1.5 | 1.25 | 17:29:20
True | 2777.884761904762 | 5693.387428571428 | 15 | -1.0 | -2.0 | 0.75 | 17:29:30
True | 2777.884761904762 | 5693.387428571428 | 15 | -1.0 | -2.0 | 1.25 | 17:29:40
True | 2777.884761904762 | 5693.387428571428 | 15 | -1.0 | -2.0 | 0.75 | 17:29:50
True | 2777.884761904762 | 5693.387428571428 | 15 | -1.0 | -1.5 | 1.25 | 17:30:00
True | 2777.884761904762 | 5693.387428571428 | 15 | -1.0 | -1.5 | 1.25 | 17:30:10
True | 2777.884761904762 | 5693.517714285714 | 15 | -1.0 | -1.5 | 1.25 | 17:30:19
True | 2777.884761904762 | 5693.387428571428 | 15 | 0.0 | -0.5 | 1.75 | 17:30:29
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

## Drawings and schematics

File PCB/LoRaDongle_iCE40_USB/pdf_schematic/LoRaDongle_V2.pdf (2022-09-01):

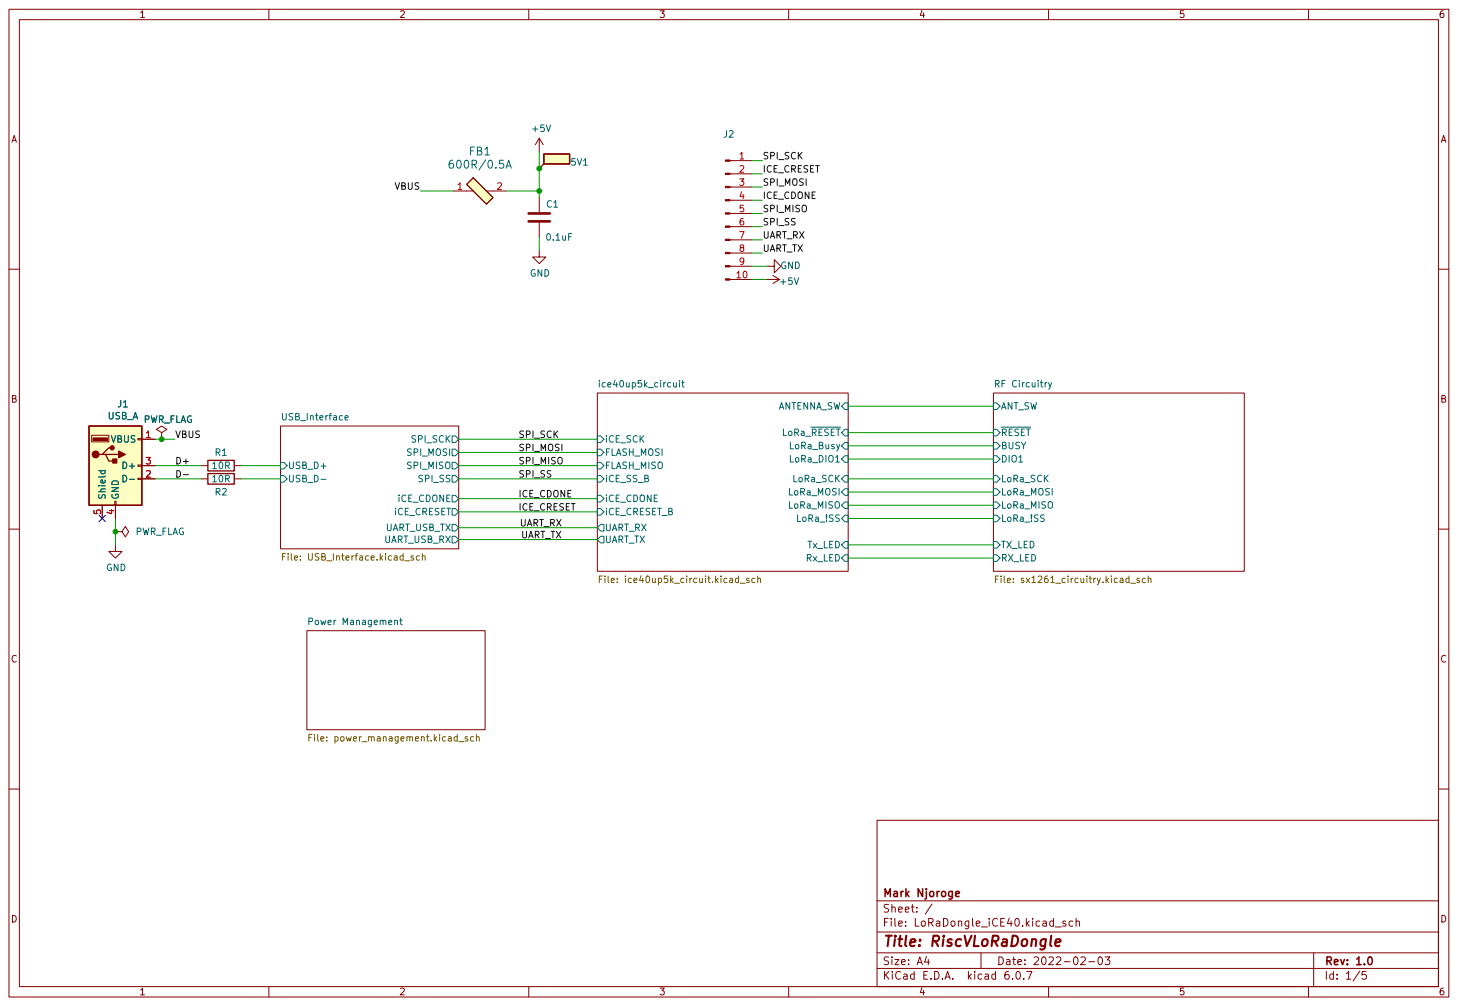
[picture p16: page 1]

File: LoRaDongle_iCE40.kicad_sch Sheet: / Mark Njoroge

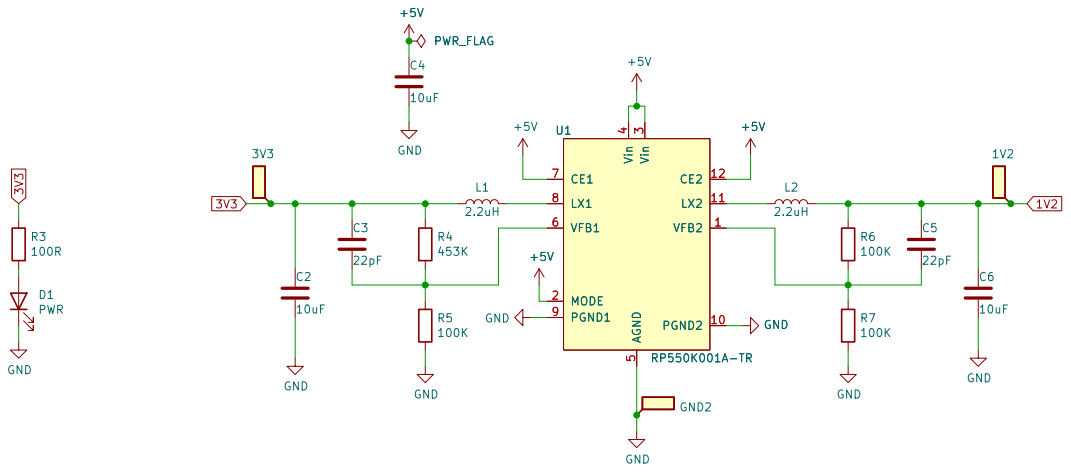
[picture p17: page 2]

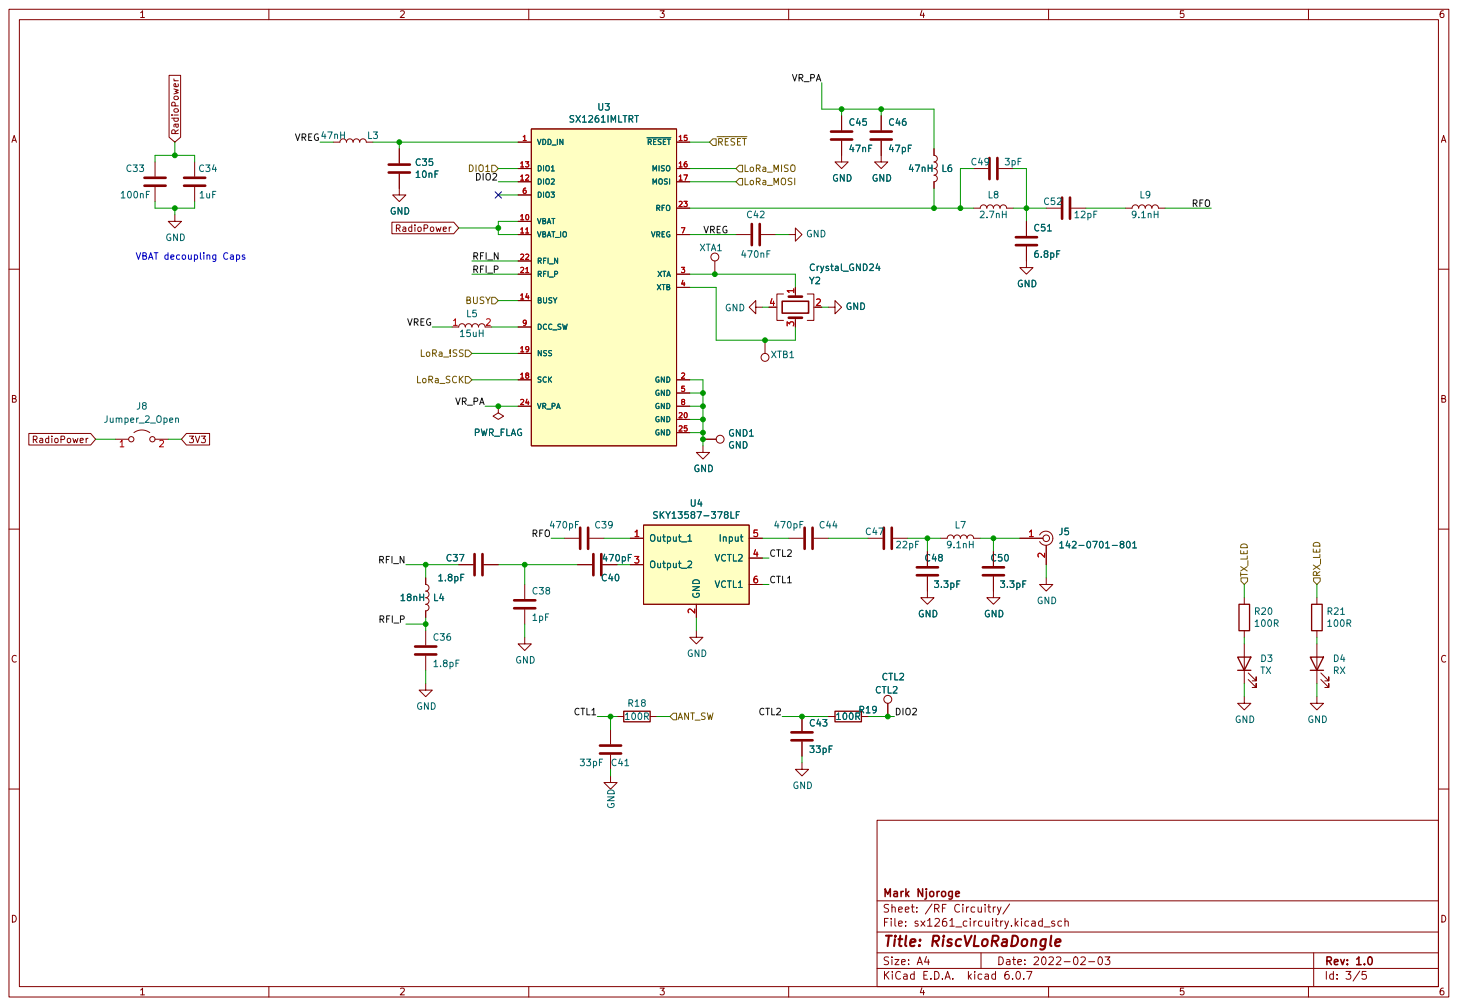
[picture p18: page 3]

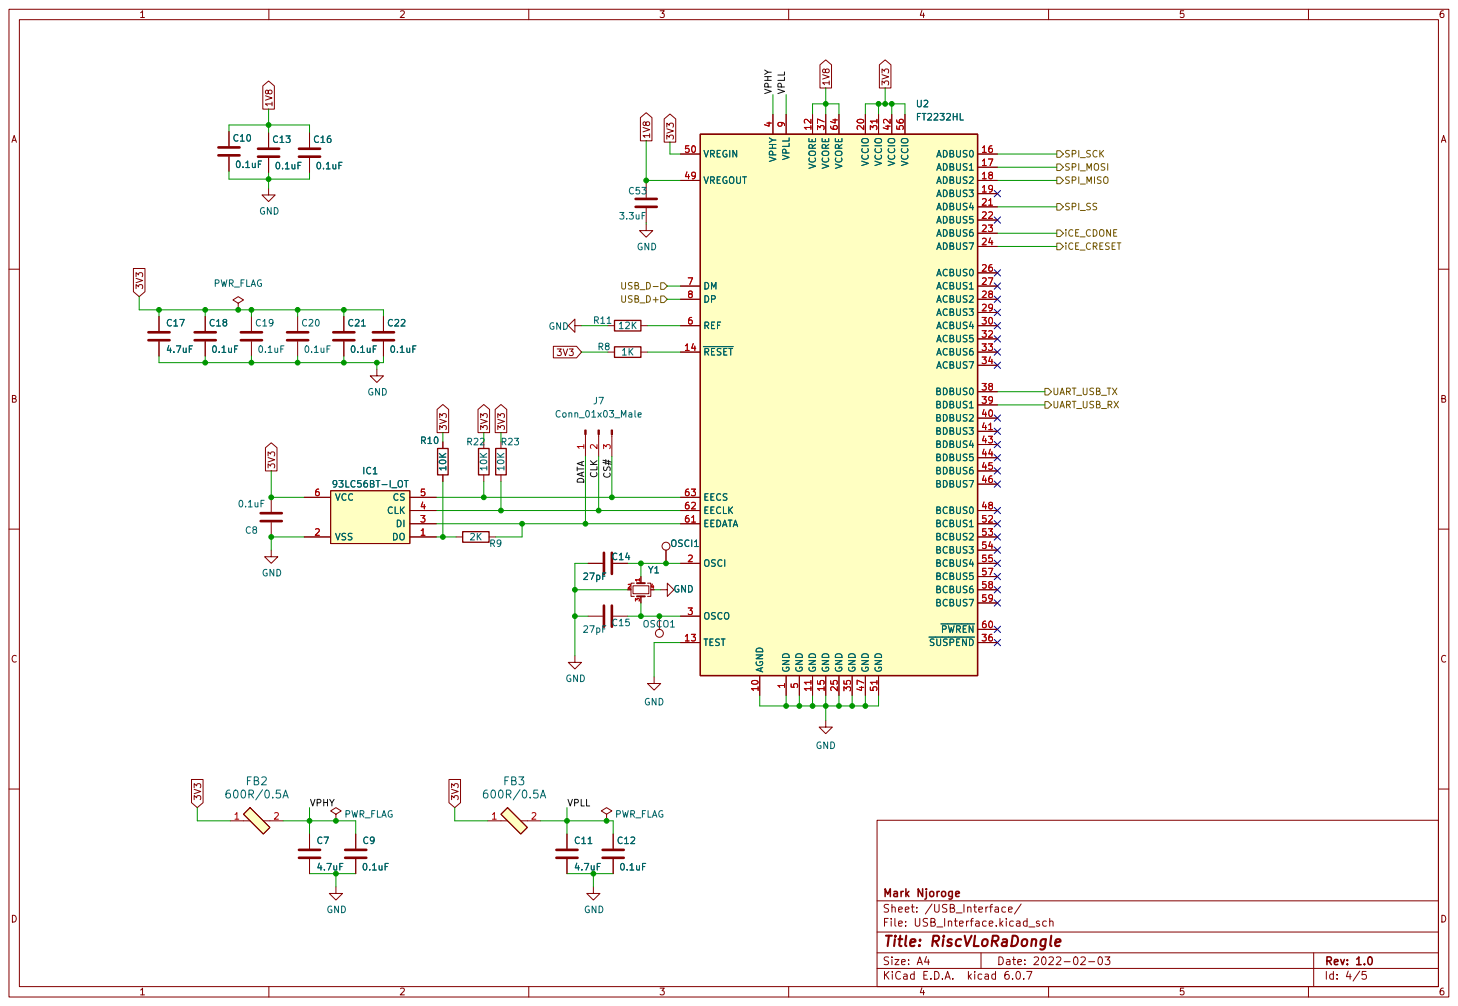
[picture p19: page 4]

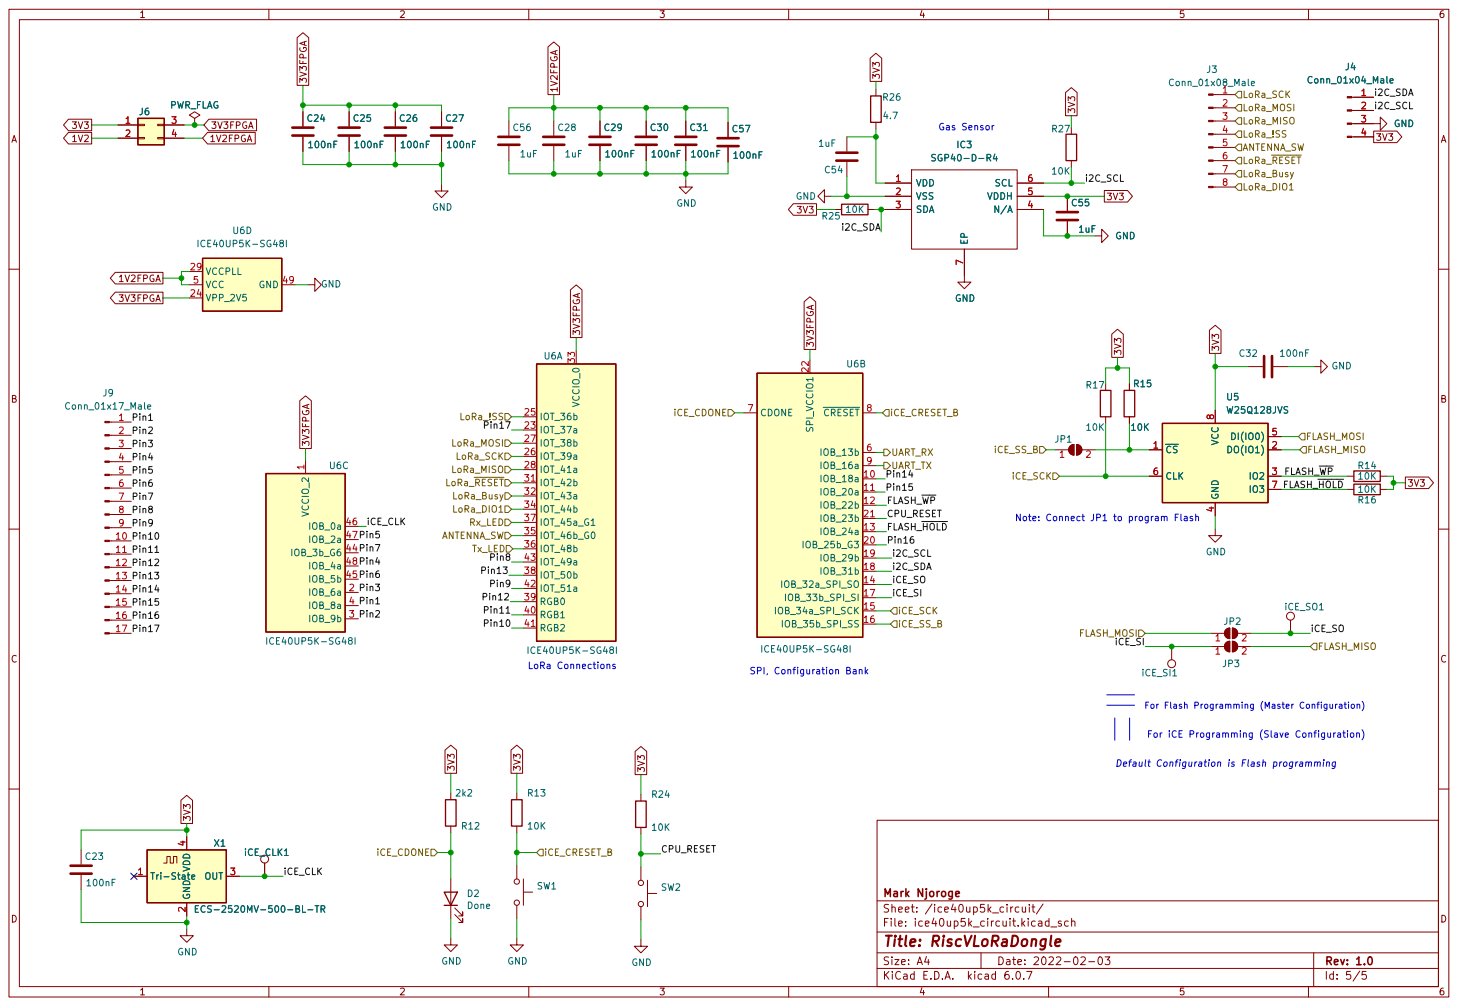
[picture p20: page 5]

8 U5W25Q128JVS C32 100nF VDD 1 VSS 2 SDA 3 N/A 4 VDDH 5 SCL 6 EP

For iCE Programming (Slave Configuration)

Default Configuration is Flash programming

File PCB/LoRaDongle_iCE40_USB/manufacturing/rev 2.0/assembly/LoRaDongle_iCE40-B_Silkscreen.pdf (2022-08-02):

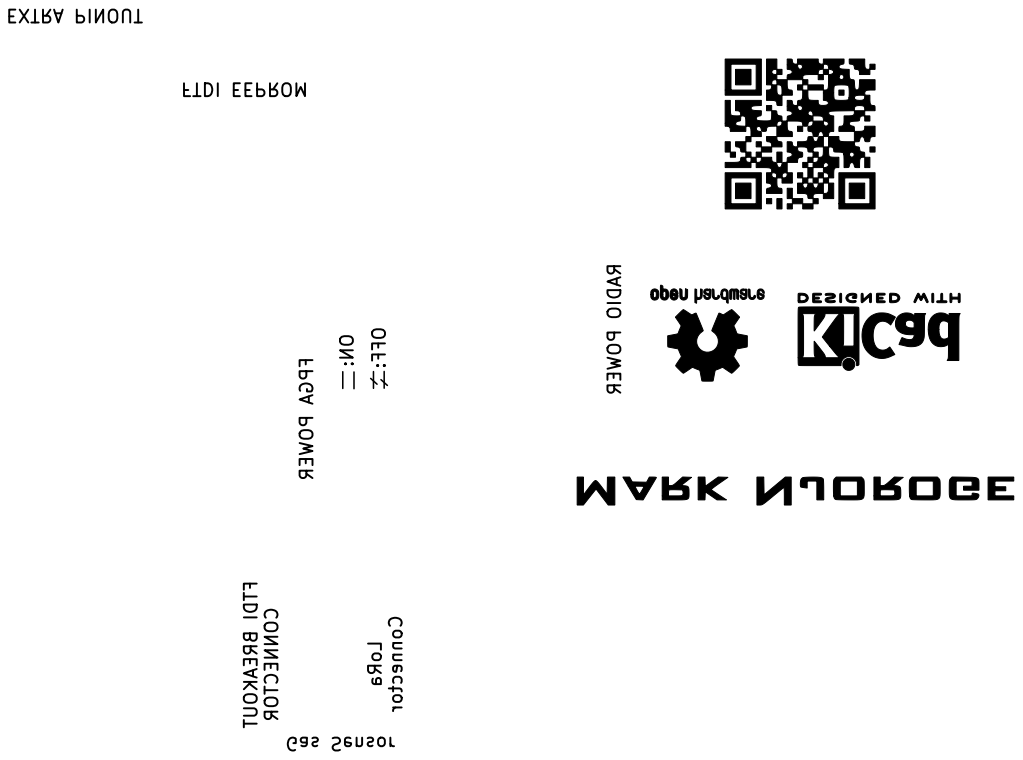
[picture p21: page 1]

Gas Sensor FPGA POWER

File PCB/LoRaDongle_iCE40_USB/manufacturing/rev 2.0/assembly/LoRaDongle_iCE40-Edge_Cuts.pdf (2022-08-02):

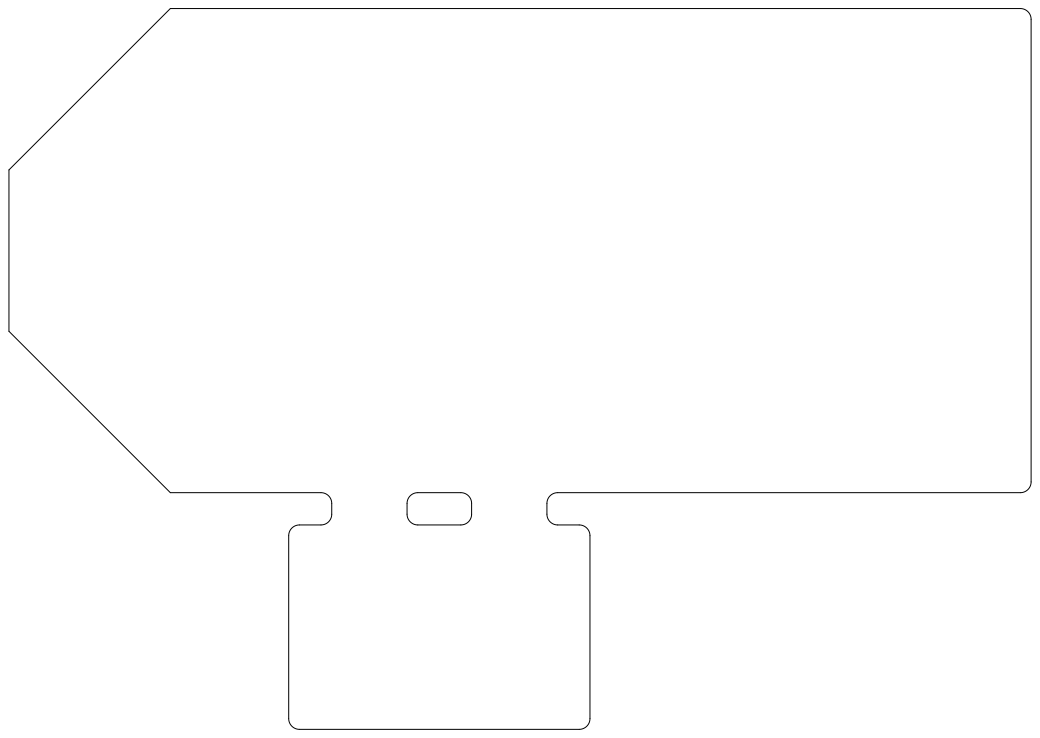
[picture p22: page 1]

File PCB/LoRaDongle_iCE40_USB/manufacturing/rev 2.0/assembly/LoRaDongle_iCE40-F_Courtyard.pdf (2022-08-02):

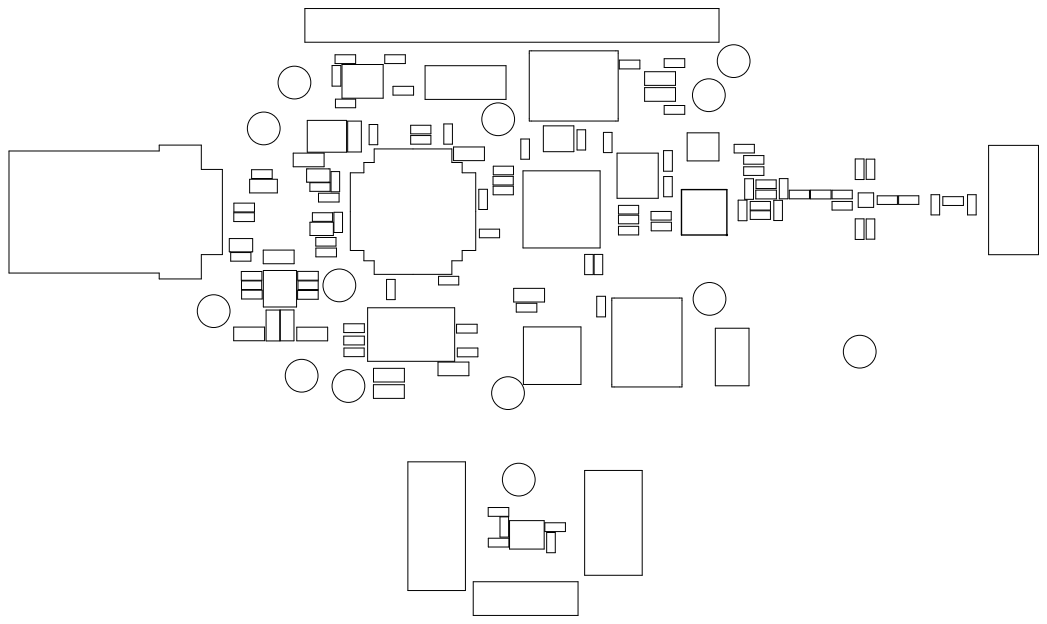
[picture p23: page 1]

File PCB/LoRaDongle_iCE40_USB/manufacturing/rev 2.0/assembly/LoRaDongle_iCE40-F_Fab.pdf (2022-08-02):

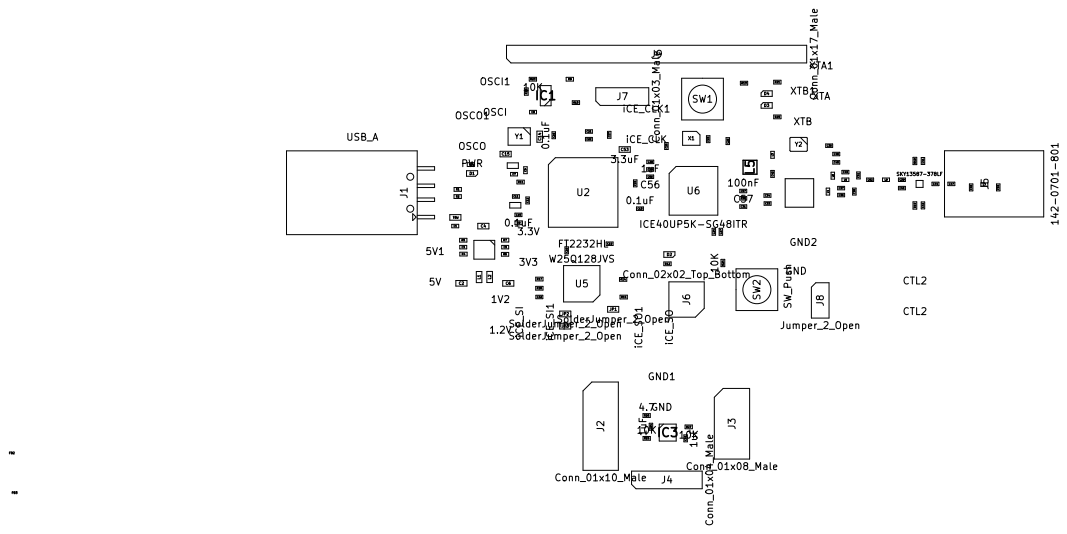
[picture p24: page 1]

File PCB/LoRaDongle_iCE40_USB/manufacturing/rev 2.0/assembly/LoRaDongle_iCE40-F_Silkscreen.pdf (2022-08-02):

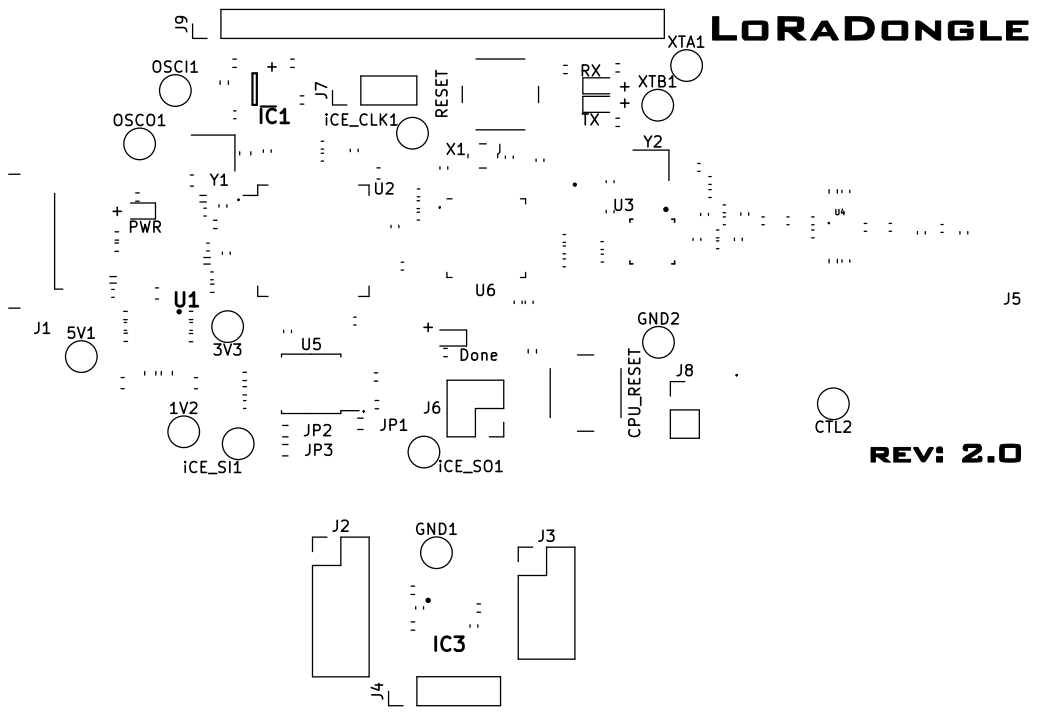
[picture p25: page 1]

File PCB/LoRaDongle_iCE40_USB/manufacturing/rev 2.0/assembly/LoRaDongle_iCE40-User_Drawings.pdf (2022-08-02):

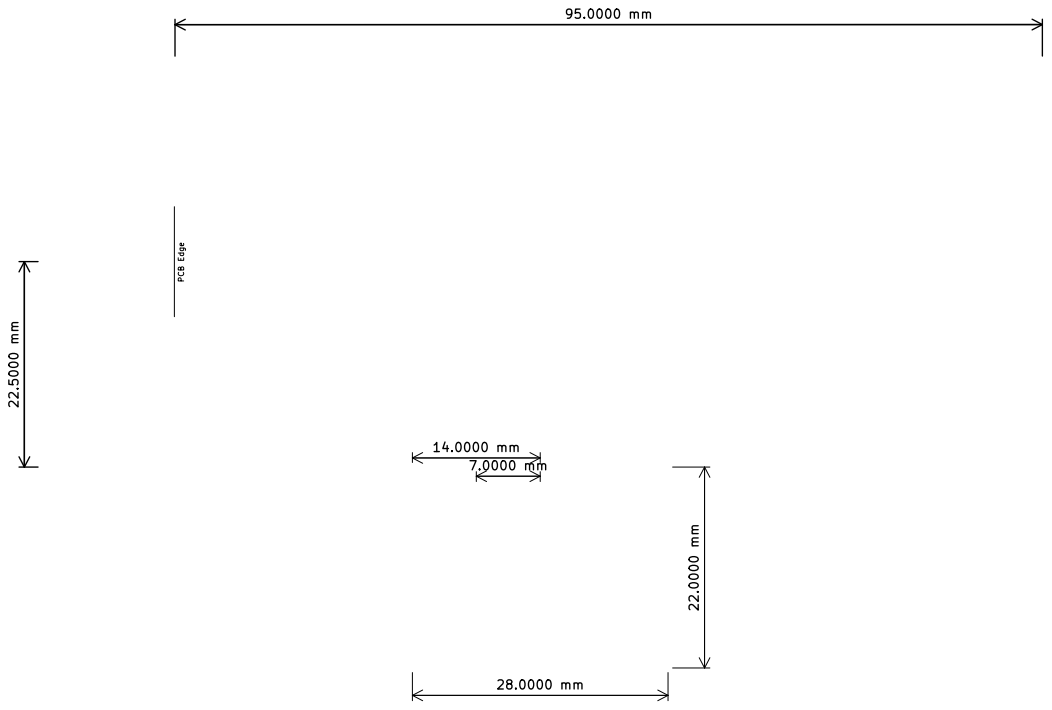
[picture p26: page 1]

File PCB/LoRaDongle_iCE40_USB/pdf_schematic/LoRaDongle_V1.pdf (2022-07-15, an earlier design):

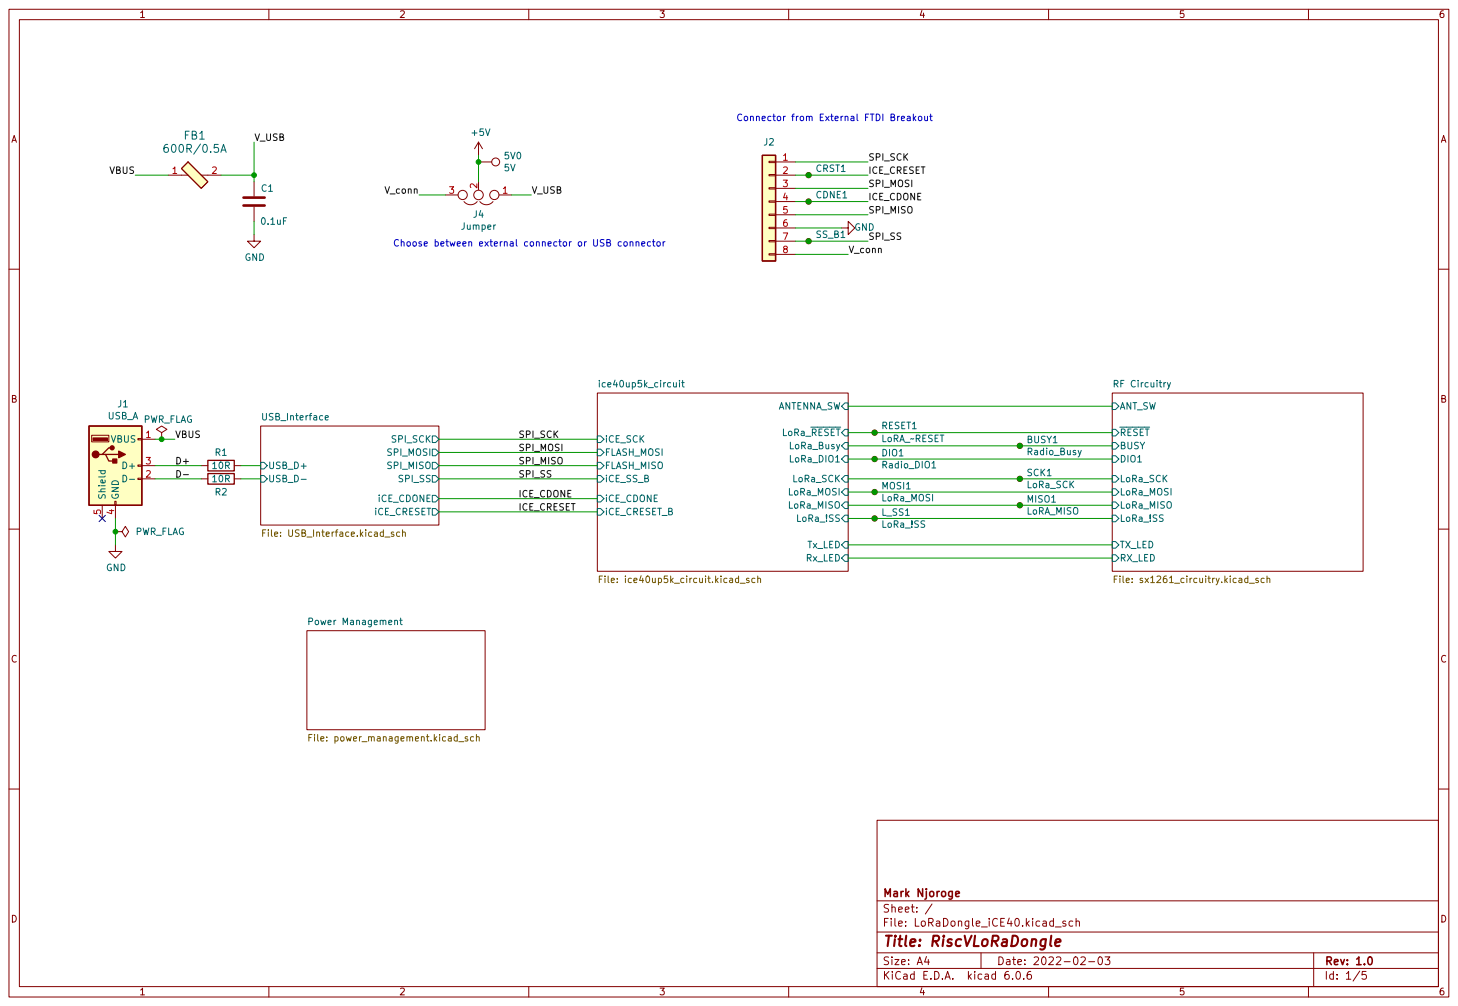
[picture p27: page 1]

File: LoRaDongle_iCE40.kicad_sch Sheet: / Mark Njoroge




4 VREGIN 40 AGND 41 TEST 42 EEDATA 43 EECLK 44 EECS 45 VCCIO 46 GND 47 GND 48 REF 5 DM 6 DP 7 VPLL

3 ACBUS6 30 ACBUS7 31 ACBUS8 32 ACBUS9 33 ~{RESET} 34 GND 35 GND 36 VCCA 37 VCCCORE 38 VCCD 39 AGND

~{RESET} Connect the LC circuits for VPHY and VLL


Note: Connect J7 to program Flash Extra Pins

iCE_SI
= For Flash Programming (Master Configuration)

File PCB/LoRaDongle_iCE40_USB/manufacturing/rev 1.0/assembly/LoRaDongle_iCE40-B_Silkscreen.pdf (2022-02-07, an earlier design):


EXTRA PINOUT FT232 BREAKOUT CONNECTOR USB

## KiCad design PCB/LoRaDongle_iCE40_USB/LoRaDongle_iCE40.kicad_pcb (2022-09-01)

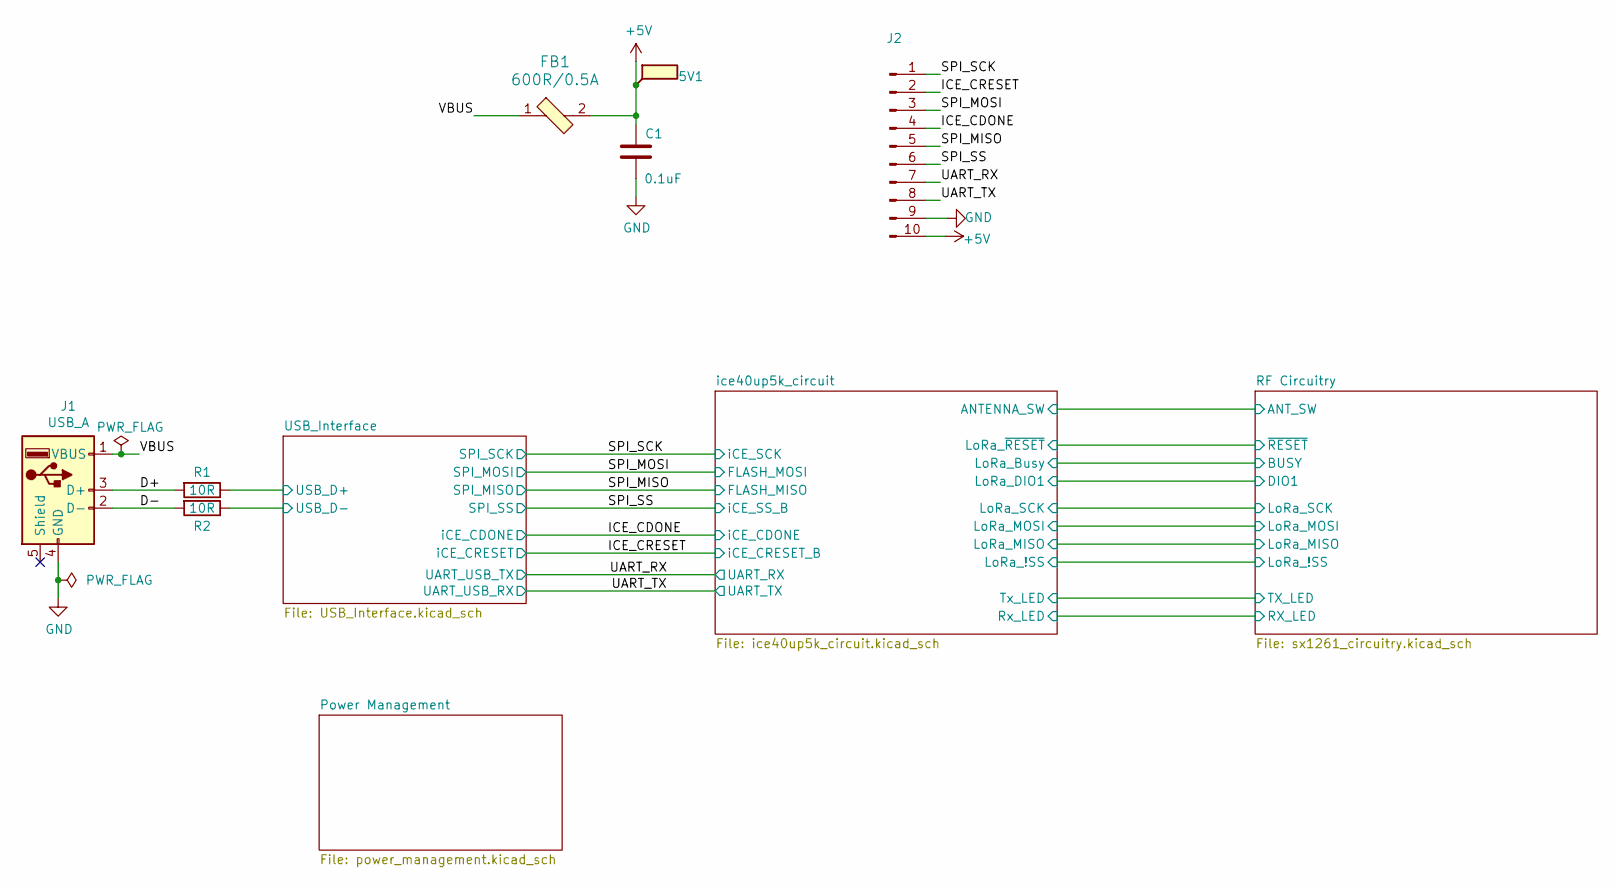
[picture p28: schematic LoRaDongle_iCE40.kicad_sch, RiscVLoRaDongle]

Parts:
5V1: 5V; TestPoint_Pad_D2.5mm
C1: 0.1uF; C_0402_1005Metric_Pad0.74x0.62mm_HandSolder; Part Number GCM155R71C104KA55J
FB1: 600R/0.5A; 0603; MPN BLM18AG601SN1D; Digi-Key_PN 490-1014-1-ND
J1: USB_A; USB_A_CNCTech_1001-011-01101_Horizontal; Manufacturer Part Number USB-AP-S-RA-SMT
J2: Conn_01x10_Male; PinHeader_2x05_P2.54mm_Vertical
R1, R2: 10R; R_0402_1005Metric_Pad0.72x0.64mm_HandSolder; Manufacturer Part Number RMCF0402FT10R0

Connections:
+5V: 5V1.1, C1.2, FB1.2, J2.10; also elsewhere on the board
/D+: J1.3 (D+), R1.2
/D-: J1.2 (D-), R2.2
/ICE_CDONE: J2.4; also elsewhere on the board
/ICE_CRESET: J2.2; also elsewhere on the board
/SPI_MISO: J2.5; also elsewhere on the board
/SPI_MOSI: J2.3; also elsewhere on the board
/SPI_SCK: J2.1; also elsewhere on the board
/SPI_SS: J2.6; also elsewhere on the board
/UART_RX: J2.7; also elsewhere on the board
/UART_TX: J2.8; also elsewhere on the board
/USB_Interface/USB_D+: R1.1; also elsewhere on the board
/USB_Interface/USB_D-: R2.1; also elsewhere on the board
/VBUS: FB1.1, J1.1 (VBUS)
GND: C1.1, J1.4 (GND), J2.9; also elsewhere on the board

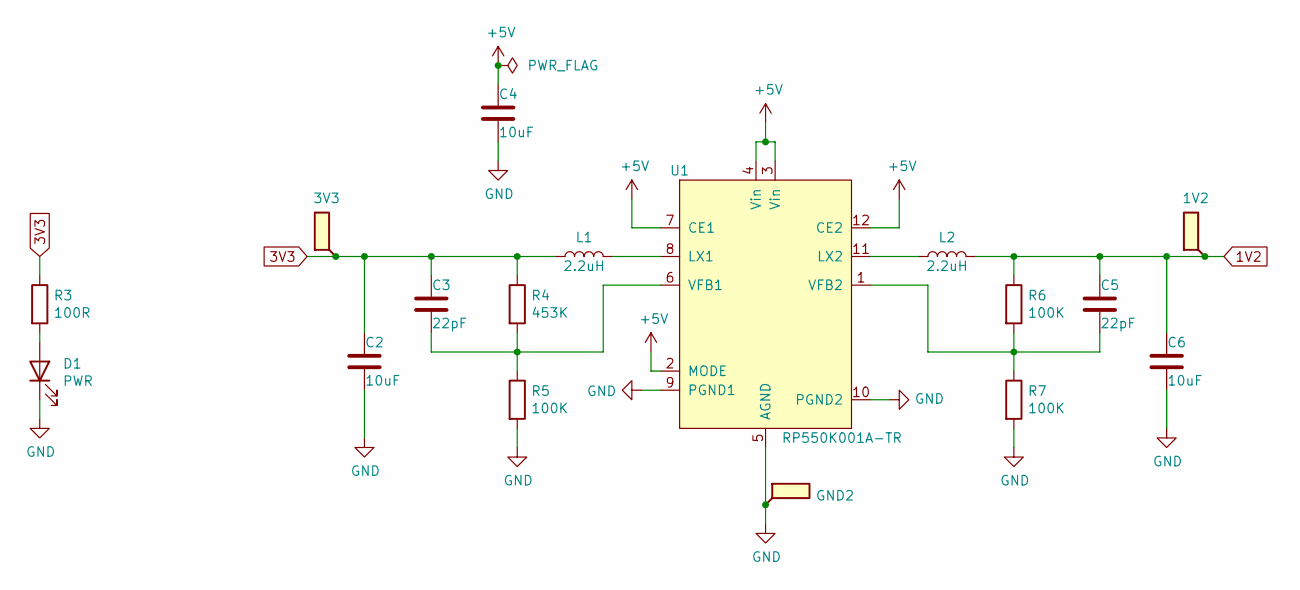
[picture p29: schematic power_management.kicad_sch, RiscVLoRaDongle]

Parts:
1V2: 1.2V; TestPoint_Pad_D2.5mm
3V3: 3.3V; TestPoint_Pad_D2.5mm
C2, C4, C6: 10uF; C_0603_1608Metric_Pad1.08x0.95mm_HandSolder; Part Number GRM188R61E106KA73J
C3, C5: 22pF; C_0402_1005Metric_Pad0.74x0.62mm_HandSolder; Part Number GRM1555C1H220FA01D
D1: PWR; LED_0603_1608Metric; Manufacturer Part Number LTST-C191KRKT
GND2: GND; TestPoint_Pad_D2.5mm
L1, L2: 2.2uH; L_0603_1608Metric_Pad1.05x0.95mm_HandSolder; Part Number MCHK1608T2R2MKN
R3: 100R; R_0402_1005Metric_Pad0.72x0.64mm_HandSolder; Manufacturer Part Number RMCF0402FT100R
R4: 453K; R_0402_1005Metric_Pad0.72x0.64mm_HandSolder; Manufacturer Part Number RMCF0402FT453K
R5, R6, R7: 100K; R_0402_1005Metric_Pad0.72x0.64mm_HandSolder; Manufacturer Part Number RMCF0402JT100K
U1: RP550K001A-TR; SON50P270X300X60-13N; Manufacturer Part Number RP550K001A-TR

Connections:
1V2: 1V2.1, C5.2, C6.2, L2.2, R6.1; also elsewhere on the board
3V3: 3V3.1, C2.2, C3.2, L1.1, R3.1, R4.1; also elsewhere on the board
+5V: C4.2, U1.2 (MODE), U1.3 (Vin), U1.4 (Vin), U1.7 (CE1), U1.12 (CE2); also elsewhere on the board
GND: C2.1, C4.1, C6.1, D1.1 (K), GND2.1, R5.2, R7.2, U1.5 (AGND), U1.9 (PGND1), U1.10 (PGND2); also elsewhere on the board
unnamed: C3.1, R4.2, R5.1, U1.6 (VFB1)
unnamed: C5.1, R6.2, R7.1, U1.1 (VFB2)
unnamed: D1.2 (A), R3.2
unnamed: L1.2, U1.8 (LX1)
unnamed: L2.1, U1.11 (LX2)

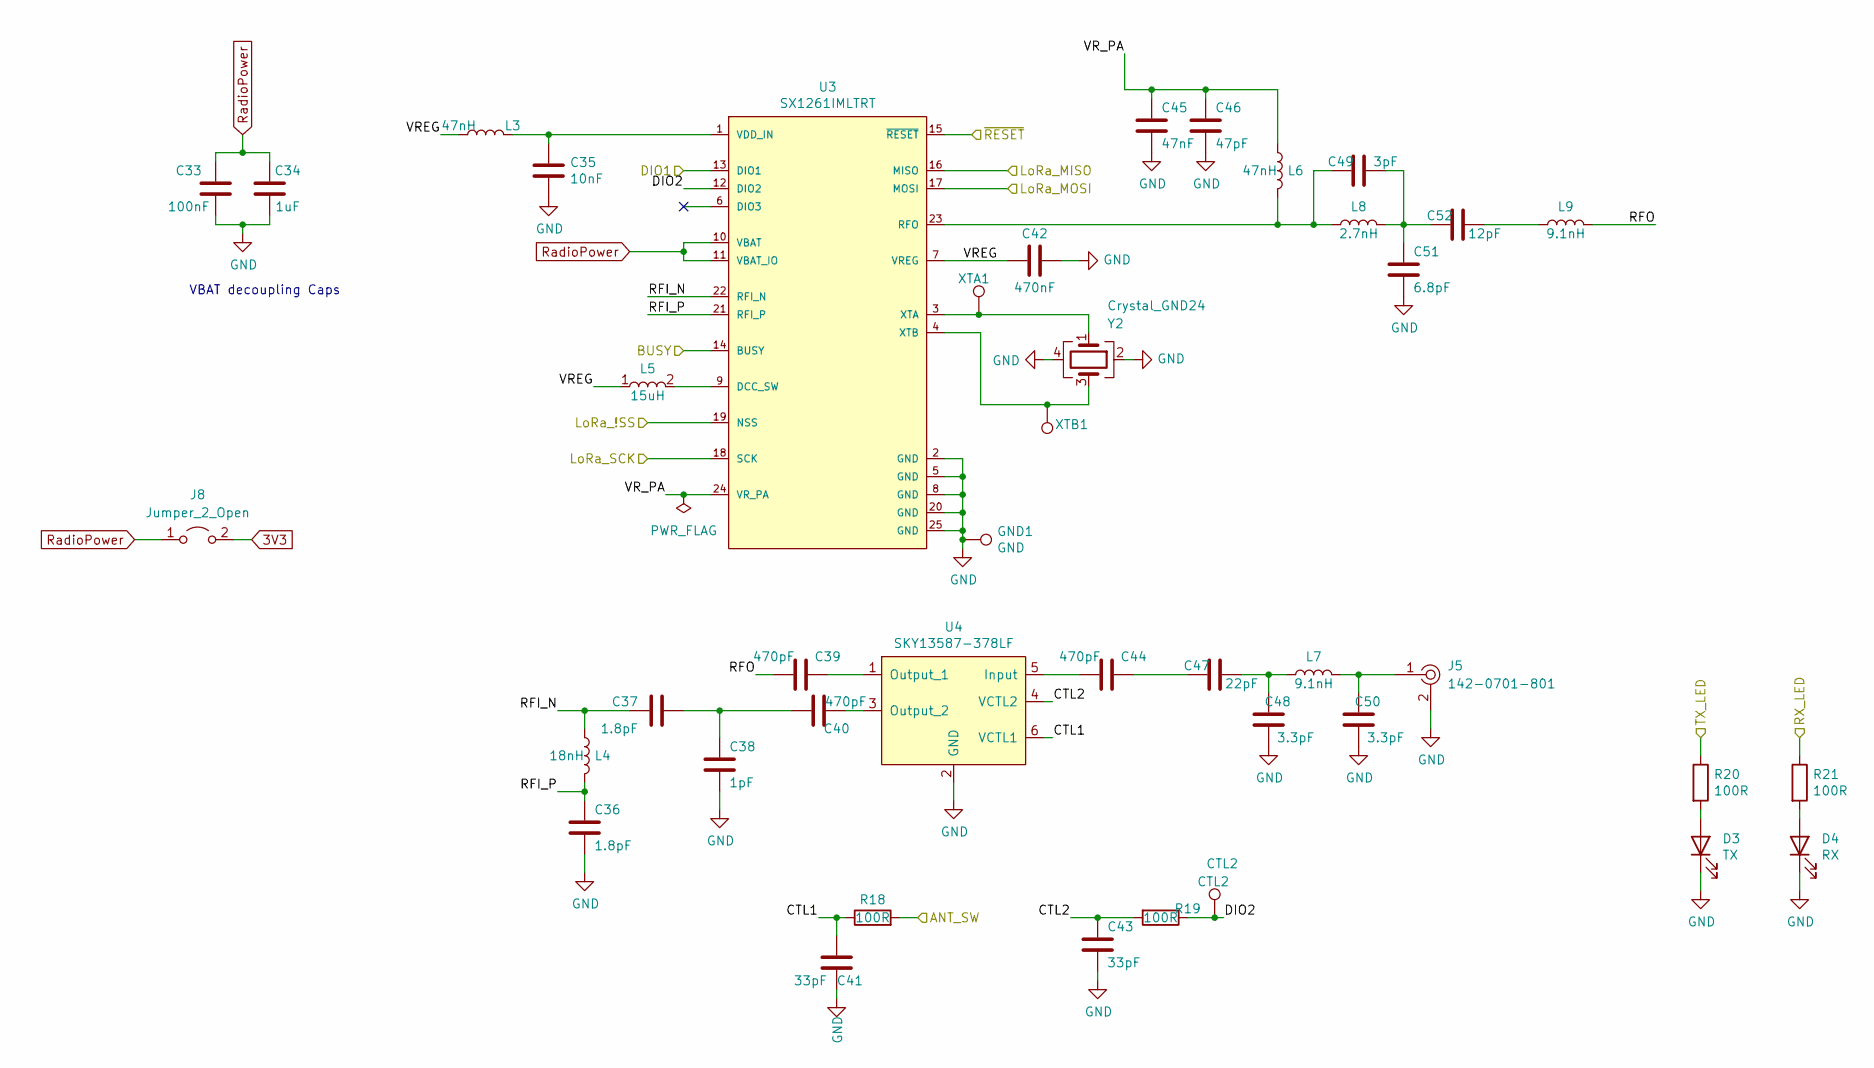
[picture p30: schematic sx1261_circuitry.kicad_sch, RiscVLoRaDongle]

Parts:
C33: 100nF; C_0402_1005Metric_Pad0.74x0.62mm_HandSolder; Part Number GRM155R71C104KA88D
C34: 1uF; C_0402_1005Metric_Pad0.74x0.62mm_HandSolder; Manufacturer Part Number GRM155R70J105MA12D
C35: 10nF; C_0402_1005Metric_Pad0.74x0.62mm_HandSolder; Part Number GRM155R71H103KA88J
C36, C37: 1.8pF; C_0402_1005Metric_Pad0.74x0.62mm_HandSolder; part Number GRM1555C1H1R8WA01D
C38: 1pF; C_0402_1005Metric_Pad0.74x0.62mm_HandSolder; part Number GRM1555C1H1R0BA01D
C39, C40, C44: 470pF; C_0402_1005Metric_Pad0.74x0.62mm_HandSolder; Part Number GRM1555C1H471JA01D
C41, C43: 33pF; C_0402_1005Metric_Pad0.74x0.62mm_HandSolder; Part Number CGA2B2C0G1H330J050BA
C42: 470nF; C_0402_1005Metric_Pad0.74x0.62mm_HandSolder; Part Number GRM155R61A474KE15D
C45: 47nF; C_0402_1005Metric_Pad0.74x0.62mm_HandSolder; Part Number GRM155R71C473KA01J
C46: 47pF; C_0402_1005Metric_Pad0.74x0.62mm_HandSolder; Part Number GRM1555C1H470JA01D
C47: 22pF; C_0402_1005Metric_Pad0.74x0.62mm_HandSolder; Part Number GRM1555C1H220JA01D
C48, C50: 3.3pF; C_0402_1005Metric_Pad0.74x0.62mm_HandSolder; Part Number GJM1555C1H3R3DB01D
C49: 3pF; C_0402_1005Metric_Pad0.74x0.62mm_HandSolder; Part Number GRM1555C1H3R0BA01J
C51: 6.8pF; C_0402_1005Metric_Pad0.74x0.62mm_HandSolder; Part Number GRM1555C1H6R8BA01D
C52: 12pF; C_0402_1005Metric_Pad0.74x0.62mm_HandSolder; Part Number GRM1555C1H120JA01J
CTL2: CTL2; TestPoint_Pad_D2.5mm
D3: TX; LED_0603_1608Metric_Pad1.05x0.95mm_HandSolder; Manufacturer Part Number XZVG53W-8
D4: RX; LED_0603_1608Metric_Pad1.05x0.95mm_HandSolder; Manufacturer Part Number XZVG53W-8
GND1: GND; TestPoint_Pad_D2.5mm
J5: 142-0701-801; RF_SMA_BoardEdge_142-0701-801; MPN 142-0701-801; Digi-Key_PN J502-ND
J8: Jumper_2_Open; PinHeader_1x02_P2.54mm_Vertical
L3: 47nH; L_0402_1005Metric_Pad0.77x0.64mm_HandSolder; PartNumber LQW15AN47NJ00D
L4: 18nH; L_0402_1005Metric_Pad0.77x0.64mm_HandSolder; part Number LQW15AN18NH00D
L5: 15uH; VLS2016; Manufacturer_Part_Number VLS201610CX-150M-1; Mouser Part Number 810-VLS201610CX150M1
L6: 47nH; L_0402_1005Metric_Pad0.77x0.64mm_HandSolder; Part Number LQW15AN47NJ00D
L7, L9: 9.1nH; L_0402_1005Metric_Pad0.77x0.64mm_HandSolder; Part Number LQW15AN9N1H00D
L8: 2.7nH; L_0402_1005Metric_Pad0.77x0.64mm_HandSolder; Part Number LQW15AN2N7C00D
R18, R19, R20, R21: 100R; R_0402_1005Metric_Pad0.72x0.64mm_HandSolder; Manufacturer Part Number RMCF0402FT100R
U3: SX1261IMLTRT; Semtech-QFN24-0-0-0; mouser part number 947-SX1261IMLTRT; digikey description TXRX LORA SUB-GHZ 15DBM 24MLPQ
U4: SKY13587-378LF; SW_SKYA21012; Manufacturer Part Number SKY13587-378LF
XTA1: XTA; TestPoint_Pad_D2.5mm
XTB1: XTB; TestPoint_Pad_D2.5mm
Y2: Crystal_GND24; Crystal_SMD_2520-4Pin_2.5x2.0mm; Part Number ECS-320-10-36B-CKM-TR

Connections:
3V3: J8.2 (B); also elsewhere on the board
/RF Circuitry/ANT_SW: R18.2; also elsewhere on the board
/RF Circuitry/BUSY: U3.14 (BUSY); also elsewhere on the board
/RF Circuitry/CTL1: C41.2, R18.1, U4.6 (VCTL1)
/RF Circuitry/CTL2: C43.1, R19.2, U4.4 (VCTL2)
/RF Circuitry/DIO1: U3.13 (DIO1); also elsewhere on the board
/RF Circuitry/DIO2: CTL2.1, R19.1, U3.12 (DIO2)
/RF Circuitry/LoRa_!SS: U3.19 (NSS); also elsewhere on the board
/RF Circuitry/LoRa_MISO: U3.16 (MISO); also elsewhere on the board
/RF Circuitry/LoRa_MOSI: U3.17 (MOSI); also elsewhere on the board
/RF Circuitry/LoRa_SCK: U3.18 (SCK); also elsewhere on the board
/RF Circuitry/RFI_N: C37.1, L4.1, U3.22 (RFI_N)
/RF Circuitry/RFI_P: C36.1, L4.2, U3.21 (RFI_P)
/RF Circuitry/RFO: C39.1, L9.2
/RF Circuitry/RX_LED: R21.1; also elsewhere on the board
/RF Circuitry/TX_LED: R20.1; also elsewhere on the board
/RF Circuitry/VREG: C42.2, L3.1, L5.1, U3.7 (VREG)
/RF Circuitry/VR_PA: C45.1, C46.1, L6.1, U3.24 (VR_PA)
/RF Circuitry/~RESET: U3.15 (~RESET); also elsewhere on the board
GND: C33.1, C34.1, C35.2, C36.2, C38.2, C41.1, C42.1, C43.2, C45.2, C46.2, C48.1, C50.1, C51.2, D3.1 (K), D4.1 (K), GND1.1, J5.2, U3.2 (GND), U3.5 (GND), U3.8 (GND), U3.20 (GND), U3.25 (GND), U4.2 (GND), Y2.2, Y2.4; also elsewhere on the board
unnamed: C35.1, L3.2, U3.1 (VDD_IN)
unnamed: C37.2, C38.1, C40.1
unnamed: C39.2, U4.1 (Output_1)
unnamed: C40.2, U4.3 (Output_2)
unnamed: C44.1, U4.5 (Input)
unnamed: C44.2, C47.2
unnamed: C47.1, C48.2, L7.1
unnamed: C49.1, C51.1, C52.2, L8.2
unnamed: C49.2, L6.2, L8.1, U3.23 (RFO)
unnamed: C50.2, J5.1, L7.2
unnamed: C52.1, L9.1
unnamed: D3.2 (A), R20.2
unnamed: D4.2 (A), R21.2
unnamed: L5.2, U3.9 (DCC_SW)
unnamed: U3.3 (XTA), XTA1.1, Y2.1
unnamed: U3.4 (XTB), XTB1.1, Y2.3
RadioPower: C33.2, C34.2, J8.1 (A), U3.10 (VBAT), U3.11 (VBAT_IO)

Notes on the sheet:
VBAT decoupling Caps

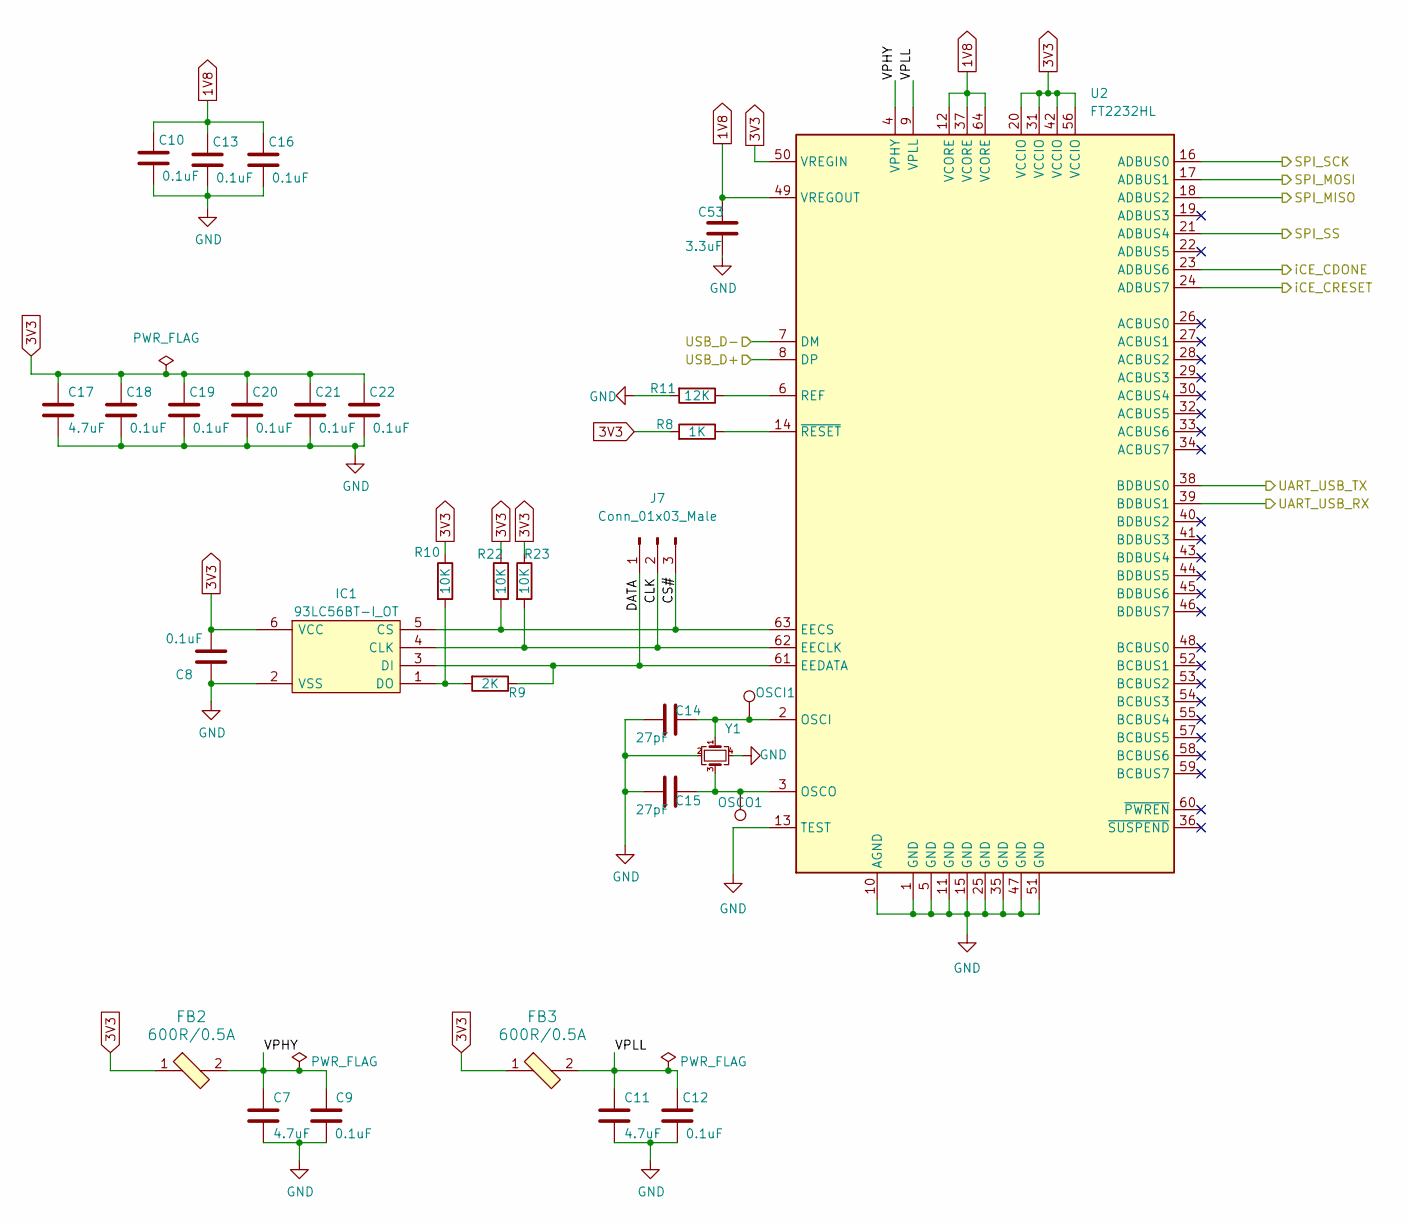
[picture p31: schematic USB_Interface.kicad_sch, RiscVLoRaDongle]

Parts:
C7, C11, C17: 4.7uF; C_0402_1005Metric_Pad0.74x0.62mm_HandSolder; Part Number GRM155C80J475MEAAD
C8, C9, C10, C12, C13, C16, C18, C19, C20, C21, C22: 0.1uF; C_0402_1005Metric_Pad0.74x0.62mm_HandSolder; Part Number GCM155R71C104KA55J
C14, C15: 27pF; C_0603_1608Metric_Pad1.08x0.95mm_HandSolder; Manufacturer Part Number GRM1885C1H270JA01D
C53: 3.3uF; C_0603_1608Metric_Pad1.08x0.95mm_HandSolder; Manufacturer Part Number CL10A335KP8NNNC
FB2, FB3: 600R/0.5A; 0603; MPN BLM18AG601SN1D; Digi-Key_PN 490-1014-1-ND
IC1: 93LC56BT-I_OT; SOT95P270X145-6N; Manufacturer_Part_Number 93LC56BT-I/OT; Mouser Part Number 579-93LC56BT-I/OT
J7: Conn_01x03_Male; PinHeader_1x03_P2.54mm_Vertical
OSCI1: OSCI; TestPoint_Pad_D2.5mm
OSCO1: OSCO; TestPoint_Pad_D2.5mm
R8: 1K; R_0402_1005Metric_Pad0.72x0.64mm_HandSolder; Manufacturer Part Number RMCF0402FT1K00
R9: 2K; R_0402_1005Metric_Pad0.72x0.64mm_HandSolder; Manufacturer Part Number RMCF0402FT2K00
R10, R22, R23: 10K; R_0402_1005Metric_Pad0.72x0.64mm_HandSolder; Manufacturer Part Number RMCF0402FT10K0
R11: 12K; R_0402_1005Metric_Pad0.72x0.64mm_HandSolder; Manufacturer Part Number RMCF0402FT12K0
U2: FT2232HL; LQFP-64_10x10mm_P0.5mm; Manufacturer Part Number FT2232HL
Y1: Crystal_GND24_Small; Crystal_SMD_3225-4Pin_3.2x2.5mm; Part Number ABM8-12.000MHZ-B2-T

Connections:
1V8: C10.2, C13.2, C16.2, C53.1, U2.12 (VCORE), U2.37 (VCORE), U2.49 (VREGOUT), U2.64 (VCORE)
3V3: C8.2, C17.1, C18.2, C19.2, C20.2, C21.2, C22.2, FB2.1, FB3.1, IC1.6 (VCC), R8.2, R10.1, R22.1, R23.1, U2.20 (VCCIO), U2.31 (VCCIO), U2.42 (VCCIO), U2.50 (VREGIN), U2.56 (VCCIO); also elsewhere on the board
/ICE_CDONE: U2.23 (ADBUS6); also elsewhere on the board
/ICE_CRESET: U2.24 (ADBUS7); also elsewhere on the board
/SPI_MISO: U2.18 (ADBUS2); also elsewhere on the board
/SPI_MOSI: U2.17 (ADBUS1); also elsewhere on the board
/SPI_SCK: U2.16 (ADBUS0); also elsewhere on the board
/SPI_SS: U2.21 (ADBUS4); also elsewhere on the board
/UART_RX: U2.38 (BDBUS0); also elsewhere on the board
/UART_TX: U2.39 (BDBUS1); also elsewhere on the board
/USB_Interface/CLK: IC1.4 (CLK), J7.2, R23.2, U2.62 (EECLK)
/USB_Interface/CS#: IC1.5 (CS), J7.3, R22.2, U2.63 (EECS)
/USB_Interface/DATA: IC1.3 (DI), J7.1, R9.1, U2.61 (EEDATA)
/USB_Interface/USB_D+: U2.8 (DP); also elsewhere on the board
/USB_Interface/USB_D-: U2.7 (DM); also elsewhere on the board
/USB_Interface/VPHY: C7.1, C9.2, FB2.2, U2.4 (VPHY)
/USB_Interface/VPLL: C11.1, C12.2, FB3.2, U2.9 (VPLL)
GND: C7.2, C8.1, C9.1, C10.1, C11.2, C12.1, C13.1, C14.2, C15.2, C16.1, C17.2, C18.1, C19.1, C20.1, C21.1, C22.1, C53.2, IC1.2 (VSS), R11.2, U2.1 (GND), U2.5 (GND), U2.10 (AGND), U2.11 (GND), U2.13 (TEST), U2.15 (GND), U2.25 (GND), U2.35 (GND), U2.47 (GND), U2.51 (GND), Y1.2, Y1.4; also elsewhere on the board
unnamed: C14.1, OSCI1.1, U2.2 (OSCI), Y1.1
unnamed: C15.1, OSCO1.1, U2.3 (OSCO), Y1.3
unnamed: IC1.1 (DO), R9.2, R10.2
unnamed: R8.1, U2.14 (~RESET)
unnamed: R11.1, U2.6 (REF)

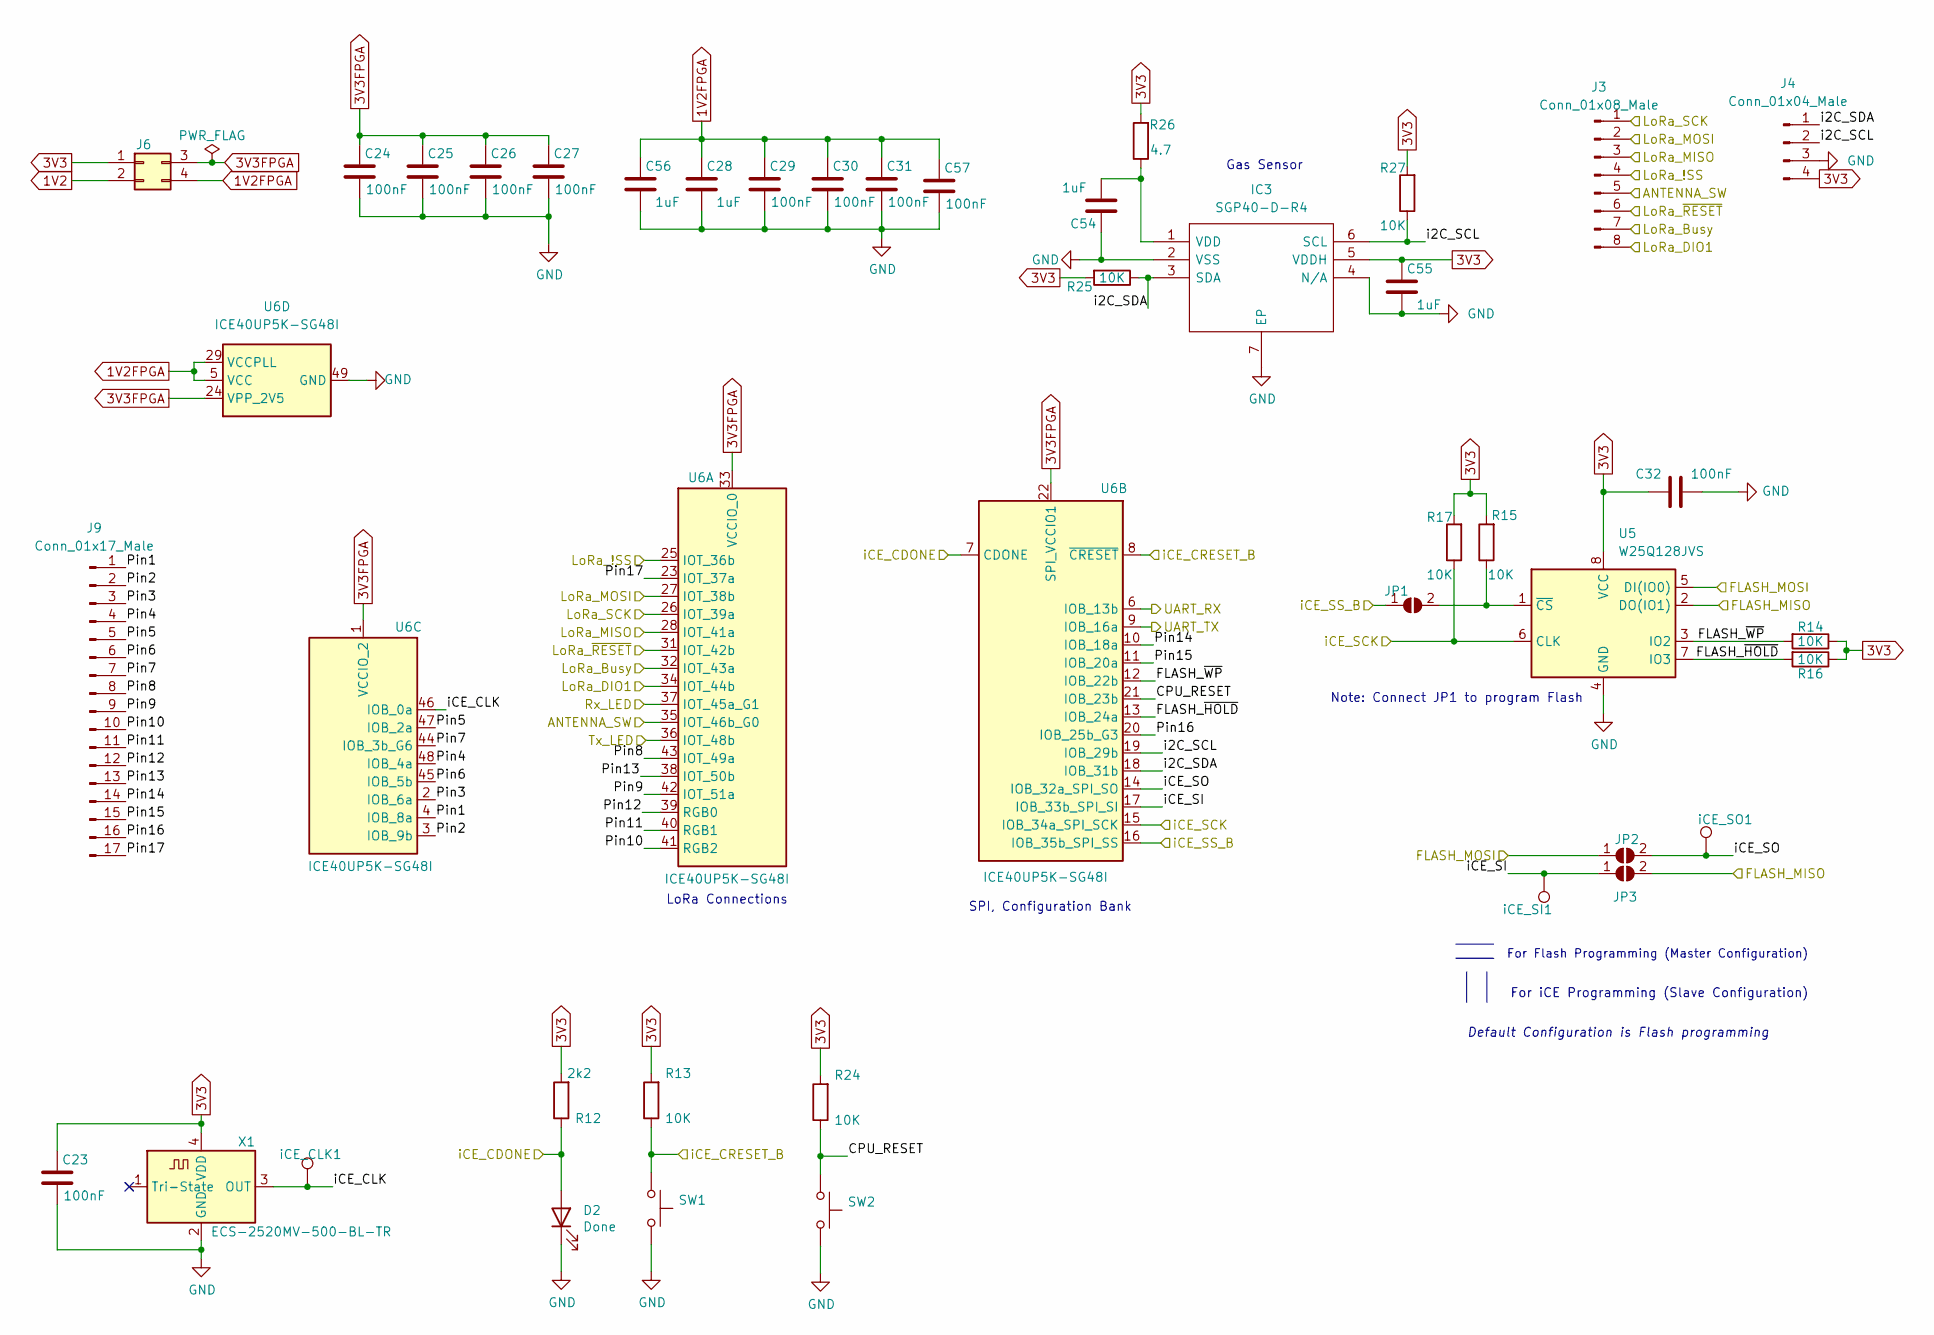
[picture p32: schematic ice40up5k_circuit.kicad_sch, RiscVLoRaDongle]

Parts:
C23, C24, C25, C26, C27, C29, C30, C31, C32, C57: 100nF; C_0402_1005Metric_Pad0.74x0.62mm_HandSolder; Part Number GRM155R71C104KA88D
C28, C54, C55, C56: 1uF; C_0402_1005Metric_Pad0.74x0.62mm_HandSolder; Part Number GRM155R70J105MA12D
D2: Done; LED_0603_1608Metric_Pad1.05x0.95mm_HandSolder; Manufacturer Part Number XZCBD53W-1
IC3: SGP40-D-R4; SON80P244X244X95-7N; Manufacturer_Part_Number SGP40-D-R4; Mouser Part Number 403-SGP40-D-R4
J3: Conn_01x08_Male; PinHeader_2x04_P2.54mm_Vertical
J4: Conn_01x04_Male; PinHeader_1x04_P2.54mm_Vertical
J6: Conn_02x02_Top_Bottom; PinHeader_2x02_P2.54mm_Vertical
J9: Conn_01x17_Male; PinHeader_1x17_P2.54mm_Vertical
JP1, JP2, JP3: SolderJumper_2_Open; R_0603_1608Metric_Pad0.98x0.95mm_HandSolder; Manufacturer Part Number RMCF0603ZT0R00
R12: 2k2; R_0402_1005Metric_Pad0.72x0.64mm_HandSolder; Manufacturer Part Number RC0402FR-072K2L
R13, R14, R15, R16, R17, R24, R25, R27: 10K; R_0402_1005Metric_Pad0.72x0.64mm_HandSolder; Manufacturer Part Number RMCF0402FT10K0
R26: 4.7; R_0402_1005Metric_Pad0.72x0.64mm_HandSolder; Manufacturer Part Number RMCF0402FT4R70
SW1, SW2: SW_Push; SW_PUSH_6mm_H5mm; Manufacturer Part Number TS02-66-55-BK-100-LCR-D
U5: W25Q128JVS; SOIC-8_5.23x5.23mm_P1.27mm; Manufacturer Part Number W25Q128JVSIM TR
U6: ICE40UP5K-SG48I; QFN-48-1EP_7x7mm_P0.5mm_EP5.6x5.6mm; Manufacturer Part Number ICE40UP5K-SG48IT
X1: ECS-2520MV-500-BL-TR; Oscillator_SMD_ECS_2520MV-xxx-xx-4Pin_2.5x2.0mm; Manufacturer Part Number ECS-2520MV-500-BL-TR
iCE_CLK1: iCE_CLK; TestPoint_Pad_D2.5mm
iCE_SI1: iCE_SI; TestPoint_Pad_D2.5mm
iCE_SO1: iCE_SO; TestPoint_Pad_D2.5mm

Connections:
1V2: J6.2; also elsewhere on the board
1V2FPGA: C28.2, C29.2, C30.2, C31.2, C56.2, C57.2, J6.4, U6.5 (VCC), U6.29 (VCCPLL), U6.30 (VCC)
3V3: C23.2, C32.2, C55.2, IC3.5 (VDDH), J4.4, J6.1, R12.2, R13.2, R14.1, R15.2, R16.1, R17.2, R24.2, R25.2, R26.2, R27.2, U5.8 (VCC), X1.4 (VDD); also elsewhere on the board
3V3FPGA: C24.2, C25.2, C26.2, C27.2, J6.3, U6.1 (VCCIO_2), U6.22 (SPI_VCCIO1), U6.24 (VPP_2V5), U6.33 (VCCIO_0)
/ICE_CDONE: D2.2 (A), R12.1, U6.7 (CDONE); also elsewhere on the board
/ICE_CRESET: R13.1, SW1.1, U6.8 (~CRESET); also elsewhere on the board
/RF Circuitry/ANT_SW: J3.5, U6.35 (IOT_46b_G0); also elsewhere on the board
/RF Circuitry/BUSY: J3.7, U6.32 (IOT_43a); also elsewhere on the board
/RF Circuitry/DIO1: J3.8, U6.34 (IOT_44b); also elsewhere on the board
/RF Circuitry/LoRa_!SS: J3.4, U6.25 (IOT_36b); also elsewhere on the board
/RF Circuitry/LoRa_MISO: J3.3, U6.28 (IOT_41a); also elsewhere on the board
/RF Circuitry/LoRa_MOSI: J3.2, U6.27 (IOT_38b); also elsewhere on the board
/RF Circuitry/LoRa_SCK: J3.1, U6.26 (IOT_39a); also elsewhere on the board
/RF Circuitry/RX_LED: U6.37 (IOT_45a_G1); also elsewhere on the board
/RF Circuitry/TX_LED: U6.36 (IOT_48b); also elsewhere on the board
/RF Circuitry/~RESET: J3.6, U6.31 (IOT_42b); also elsewhere on the board
/SPI_MISO: JP3.2 (B), U5.2 (DO(IO1)); also elsewhere on the board
/SPI_MOSI: JP2.1 (A), U5.5 (DI(IO0)); also elsewhere on the board
/SPI_SCK: R17.1, U5.6 (CLK), U6.15 (IOB_34a_SPI_SCK); also elsewhere on the board
/SPI_SS: JP1.1 (A), U6.16 (IOB_35b_SPI_SS); also elsewhere on the board
/UART_RX: U6.6 (IOB_13b); also elsewhere on the board
/UART_TX: U6.9 (IOB_16a); also elsewhere on the board
/ice40up5k_circuit/CPU_RESET: R24.1, SW2.1, U6.21 (IOB_23b)
/ice40up5k_circuit/FLASH_~HOLD: R16.2, U5.7 (IO3), U6.13 (IOB_24a)
/ice40up5k_circuit/FLASH_~WP: R14.2, U5.3 (IO2), U6.12 (IOB_22b)
/ice40up5k_circuit/Pin1: J9.1, U6.4 (IOB_8a)
/ice40up5k_circuit/Pin2: J9.2, U6.3 (IOB_9b)
/ice40up5k_circuit/Pin3: J9.3, U6.2 (IOB_6a)
/ice40up5k_circuit/Pin4: J9.4, U6.48 (IOB_4a)
/ice40up5k_circuit/Pin5: J9.5, U6.47 (IOB_2a)
/ice40up5k_circuit/Pin6: J9.6, U6.45 (IOB_5b)
/ice40up5k_circuit/Pin7: J9.7, U6.44 (IOB_3b_G6)
/ice40up5k_circuit/Pin8: J9.8, U6.43 (IOT_49a)
/ice40up5k_circuit/Pin9: J9.9, U6.42 (IOT_51a)
/ice40up5k_circuit/Pin10: J9.10, U6.41 (RGB2)
/ice40up5k_circuit/Pin11: J9.11, U6.40 (RGB1)
/ice40up5k_circuit/Pin12: J9.12, U6.39 (RGB0)
/ice40up5k_circuit/Pin13: J9.13, U6.38 (IOT_50b)
/ice40up5k_circuit/Pin14: J9.14, U6.10 (IOB_18a)
/ice40up5k_circuit/Pin15: J9.15, U6.11 (IOB_20a)
/ice40up5k_circuit/Pin16: J9.16, U6.20 (IOB_25b_G3)
/ice40up5k_circuit/Pin17: J9.17, U6.23 (IOT_37a)
/ice40up5k_circuit/i2C_SCL: IC3.6 (SCL), J4.2, R27.1, U6.19 (IOB_29b)
/ice40up5k_circuit/i2C_SDA: IC3.3 (SDA), J4.1, R25.1, U6.18 (IOB_31b)
/ice40up5k_circuit/iCE_CLK: U6.46 (IOB_0a), X1.3 (OUT), iCE_CLK1.1
/ice40up5k_circuit/iCE_SI: JP3.1 (A), U6.17 (IOB_33b_SPI_SI), iCE_SI1.1
/ice40up5k_circuit/iCE_SO: JP2.2 (B), U6.14 (IOB_32a_SPI_SO), iCE_SO1.1
GND: C23.1, C24.1, C25.1, C26.1, C27.1, C28.1, C29.1, C30.1, C31.1, C32.1, C54.2, C55.1, C56.1, C57.1, D2.1 (K), IC3.2 (VSS), IC3.4 (N/A), IC3.7 (EP), J4.3, SW1.2, SW2.2, U5.4 (GND), U6.49 (GND), X1.2 (GND); also elsewhere on the board
unnamed: C54.1, IC3.1 (VDD), R26.1
unnamed: JP1.2 (B), R15.1, U5.1 (~CS)

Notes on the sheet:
LoRa Connections
Gas Sensor
SPI, Configuration Bank
Note: Connect JP1 to program Flash
For Flash Programming (Master Configuration)
Default Configuration is Flash programming
For iCE Programming (Slave Configuration)

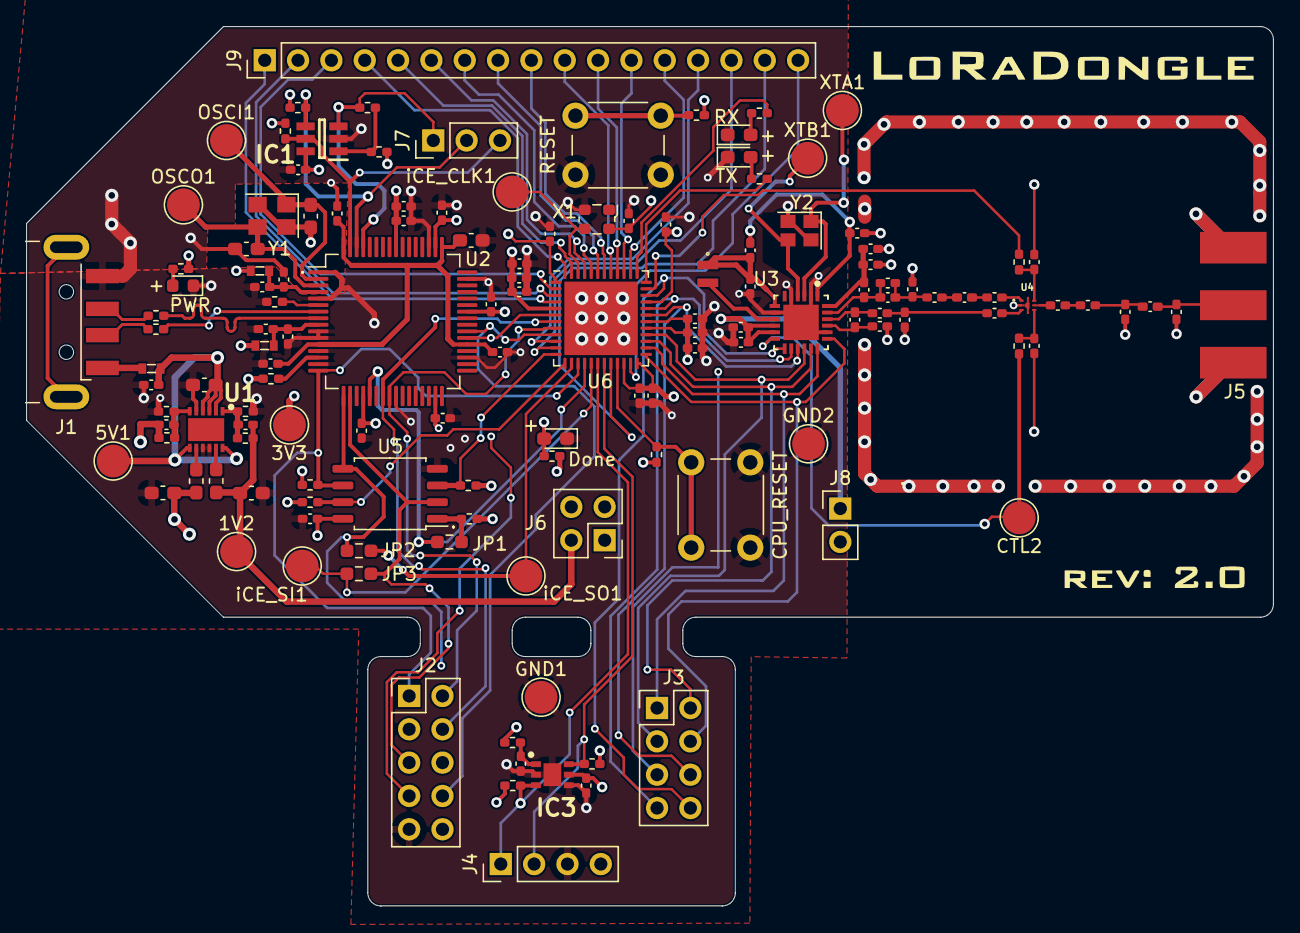
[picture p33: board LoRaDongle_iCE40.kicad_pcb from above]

Board: 4 copper layers, 95.0 x 67.0 mm, 140 parts (1 on the bottom side), 97 nets.

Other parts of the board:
G1: LOGO; LoRaDongleLogo
G3: LOGO; mark_njoroge

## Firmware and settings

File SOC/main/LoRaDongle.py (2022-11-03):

#!/usr/bin/env python3

# This file is Copyright (c) 2019 Sean Cross <sean@xobs.io>
# This file is Copyright (c) 2018 David Shah <dave@ds0.me>
# This file is Copyright (c) 2020 Piotr Esden-Tempski <piotr@esden.net>
# This file is Copyright (c) 2022 Mark Njoroge <marksnjoroge@gmail.com>
# License: BSD

# This target was derived from the icebreaker-litex-examples SOC

import argparse
from os import path

from migen import *
from migen.genlib.resetsync import AsyncResetSynchronizer
from migen.genlib.io import CRG

from litex.soc.cores.ram import Up5kSPRAM
#from litex.soc.cores.spi_flash import SpiFlash
from litex.soc.cores.clock import iCE40PLL
from litex.soc.integration.soc_core import SoCCore
from litex.soc.integration.builder import Builder, builder_argdict, builder_args
from litex.build.lattice.programmer import IceStormProgrammer
from litex.soc.integration.soc_core import soc_core_argdict, soc_core_args
from litex.soc.integration.doc import AutoDoc
from litex.soc.integration.soc import SoCRegion


#from Platform.LoRaDongleV1 import Platform
from Platform.LoRaDongleV2 import Platform

from litex.soc.cores.uart import UARTWishboneBridge
from litex.soc.cores import gpio
from litex.soc.cores.spi import SPIMaster
from litex.soc.cores.bitbang import I2CMaster

import litex.soc.doc as lxsocdoc


# CRG ----------------------------------------------------------------------------------------------


class _CRG(Module, AutoDoc):
    """LoRaDongle Clock Resource Generator, pulled from Icebreaker

    The system is clocked by the external 50MHz clock. But if a sys_clk_freq is set to a value
    that is different from the default 50MHz we will feed it through the PLL block and try to
    generate a clock as close as possible to the selected frequency.
    """
    def __init__(self, platform, sys_clk_freq):
        self.clock_domains.cd_sys = ClockDomain()
        self.clock_domains.cd_por = ClockDomain()

        # # #

        # Clocks
        clk = platform.request("clk")
        if sys_clk_freq == 50e6:
            self.comb += self.cd_sys.clk.eq(clk)
        else:
            self.submodules.pll = pll = iCE40PLL(primitive="SB_PLL40_CORE")
            pll.register_clkin(clk, 50e6)
            pll.create_clkout(self.cd_sys, sys_clk_freq, with_reset=False)
        platform.add_period_constraint(self.cd_sys.clk, 1e9 / sys_clk_freq)

        # Power On Reset
        self.reset = Signal()
        por_cycles = 4096
        por_counter = Signal(log2_int(por_cycles), reset=por_cycles - 1)
        self.comb += self.cd_por.clk.eq(self.cd_sys.clk)
        platform.add_period_constraint(self.cd_por.clk, 1e9 / sys_clk_freq)
        self.sync.por += If(por_counter != 0, por_counter.eq(por_counter - 1))
        self.comb += self.cd_sys.rst.eq(por_counter != 0)
        self.specials += AsyncResetSynchronizer(self.cd_por, self.reset)


# BaseSoC ------------------------------------------------------------------------------------------

class BaseSoC(SoCCore):
    """A SoC on LoRaDongle, optionally with a softcore CPU"""

    # Statically-define the memory map, to prevent it from shifting across various litex versions.
    SoCCore.mem_map = {
        "sram":             0x10000000,
        "spiflash":         0x20000000,
        "csr":              0xf0000000,
    }

    def __init__(self, cpu, debug, flash_offset, sys_clk_freq, **kwargs):
        """Create a basic SoC for LoRaDongle.

        Create a basic SoC for LoRaDongle.  The `sys` frequency will run at 21 MHz.

        Returns:
            Newly-constructed SoC
        """
        platform = Platform()
        
        if cpu == "serv":
            kwargs["cpu_type"] = "serv"
        elif cpu == "picorv32":
            kwargs["cpu_type"] = "picorv32"
            #variant defaults when none are provided
            if "cpu_variant" not in kwargs:
                kwargs["cpu_variant"] = "minimal"
        
        # Force the SRAM size to 0, because we add our own SRAM with SPRAM
        kwargs["integrated_sram_size"] = 0
        kwargs["integrated_rom_size"]  = 0

        kwargs["csr_data_width"] = 32

        # Set CPU reset address
        kwargs["cpu_reset_address"] = self.mem_map["spiflash"] + flash_offset

        # Select "crossover" as soc uart instead of "serial"
        # We have to make that selection before calling the parent initializer
        if debug:
            kwargs["uart_name"]   = "crossover"

        # SoCCore
        SoCCore.__init__(self, platform, sys_clk_freq, **kwargs)

        self.submodules.crg = _CRG(platform, sys_clk_freq)
        #self.submodules.crg = CRG(platform.request("clk"), ~platform.request("cpu_reset"))


        # UP5K has single port RAM, which is a dedicated 128 kilobyte block.
        # Use this as CPU RAM.
        spram_size = 128 * 1024
        self.submodules.spram = Up5kSPRAM(size=spram_size)
        self.register_mem("sram", self.mem_map["sram"], self.spram.bus, spram_size)


        #spi_clk = platform.request("spi_clk")       # CLock for SPI SIgnals


        # SPI Flash --------------------------------------------------------------------------------
        from litespi.modules import W25Q128JV
        from litespi.opcodes import SpiNorFlashOpCodes as Codes
        self.add_spi_flash(mode="1x", module=W25Q128JV(Codes.READ_1_1_1), with_master=False)


        #from litespi.modules import N25Q032A
        #from litespi.phy.generic import LiteSPIPHY
        
        #spi_flash_pads = platform.request("spiflash")
        #spi_flash_pads.clk = Signal()
        #spiflash_phy = LiteSPIPHY(spi_flash_pads, N25Q032A(Codes.READ_1_1_1), device=self.platform.device, default_divisor=1)
        #setattr(self.submodules, name + "_phy",  spiflash_phy)
        
        #self.add_spi_flash(phy=spiflash_phy,mode="1x", module=N25Q032A(Codes.READ_1_1_1), with_master=False)
        
        #self.add_spi_flash(mode="1x", module=N25Q032A(Codes.READ_1_1_1), with_master=False)



        # Add ROM linker region --------------------------------------------------------------------
        self.bus.add_region("rom", SoCRegion(
            origin = self.mem_map["spiflash"] + flash_offset,
            size   = 8*1024*1024, 
            linker = True)
        )

        # In debug mode, add a UART bridge.  This takes over from the normal UART bridge,
        # however you can use the "crossover" UART to communicate with this over the bridge.
        if debug:
            self.submodules.uart_bridge = UARTWishboneBridge(
                platform.request("serial"), 
                sys_clk_freq, 
                baudrate=115200)
            self.add_wb_master(self.uart_bridge.wishbone)

        #Adding Timer for Tests
        from litex.soc.cores.timer import Timer
        self.submodules.timer1 = Timer()
        if cpu != "serv":
            self.add_interrupt("timer1")
        self.add_csr("timer1")


        # Leds
        user_leds = Cat(*[platform.request("user_led", i) for i in range(2)])
        self.submodules.leds = gpio.GPIOOut(user_leds)
        self.add_csr("leds")


        #Input Button Interrupt
        self.submodules.btn = gpio.GPIOIn(platform.request("btn"), with_irq = self.irq.enabled )
        if cpu != "serv":
            self.add_interrupt("btn")
        self.add_csr("btn")


         
        #####LoRa Pins#####
        #Busy Input Pin
        self.submodules.lora_busy = gpio.GPIOIn(platform.request("lora_busy"))
        self.add_csr("lora_busy")

        #DIO Input Interrupt ptin
        self.submodules.dio1 = gpio.GPIOIn(platform.request("dio1"), with_irq = self.irq.enabled )
        if cpu != "serv":
            self.add_interrupt("dio1")
        self.add_csr("dio1")

        #Output Pins
        #Combined Register names - differentiation of pins in software
        lora_config = Cat(*[platform.request("lora_config", i) for i in range(2)])
        self.submodules.lora_config = gpio.GPIOOut(lora_config)
        self.add_csr("lora_config")

        # SPI
        self.submodules.SPI = SPIMaster(platform.request("spi_bus", 0),
            data_width = 8,
            sys_clk_freq = sys_clk_freq,
            spi_clk_freq = 8e6)
        self.add_csr("spi_bus")


        ######### Gas Sensor ##############
        #I2CMaster
        self.submodules.i2c = I2CMaster(platform.request("i2c_bus"))
        self.add_csr("i2c")

        #spi_pads = platform.lookup_request("clk")
        #spi_pads = platform.request("spi_bus", 0)
        #spi_bus_pads = platform.request("spi_bus")
        #spi_bus_pads.clk = Signal()
        #self.submodules.SPI = SPIMaster(spi_bus_pads,
            #data_width = 8,
            #sys_clk_freq = sys_clk_freq,
            #spi_clk_freq = 8e6)
        #self.add_csr("spi_bus")

        #self.comb += spi_clk.eq(spi_flash_pads.clk | spi_bus_pads.clk) #Connecting SPI Clock to both SPIMaster and SPIFlash
        #self.comb += spi_clk.eq(spi_flash_pads.clk)
        #self.comb += spi_clk.eq(spi_bus_pads.clk)


    def set_yosys_nextpnr_settings(self, nextpnr_seed=0, nextpnr_placer="heap"):
        """Set Yosys/Nextpnr settings by overriding default LiteX's settings.
        Args:
            nextpnr_seed   (int): Seed to use in Nextpnr
            nextpnr_placer (str): Placer to use in Nextpnr
        """
        assert hasattr(self.platform.toolchain, "yosys_template")
        assert hasattr(self.platform.toolchain, "build_template")
        self.platform.toolchain.yosys_template = [
            "{read_files}",
            "attrmap -tocase keep -imap keep=\"true\" keep=1 -imap keep=\"false\" keep=0 -remove keep=0",
            # Use "-relut -dffe_min_ce_use 4" to the synth_ice40 command. The "-reult" adds an additional
            # LUT pass to pack more stuff in, and the "-dffe_min_ce_use 4" flag prevents Yosys from
            # generating a Clock Enable signal for a LUT that has fewer than 4 flip-flops. This increases
            # density, and lets us use the FPGA more efficiently.
            "synth_ice40 -json {build_name}.json -top {build_name} -relut -abc2 -dffe_min_ce_use 4 -relut",
        ]
        self.platform.toolchain.build_template = [
            "yosys -q -l {build_name}.rpt {build_name}.ys",
            "nextpnr-ice40 --json {build_name}.json --pcf {build_name}.pcf --asc {build_name}.txt" +
            " --pre-pack {build_name}_pre_pack.py --{architecture} --package {package}" +
            " --seed {}".format(nextpnr_seed) +
            " --placer {}".format(nextpnr_placer),
            # Disable final deep-sleep power down so firmware words are loaded onto softcore's address bus.
            "icepack -s {build_name}.txt {build_name}.bin"
        ]



# Build --------------------------------------------------------------------------------------------

def main():
    parser = argparse.ArgumentParser(description="LiteX SoC on LoRaDongle")
    parser.add_argument("--cpu", default="picorv32", help="Select CPY type")
    parser.add_argument("--flash-offset", default=0x20000, help="Boot offset in SPI Flash")
    parser.add_argument("--sys-clk-freq", type=float, default=21e6, help="Select system clock frequency")
    parser.add_argument("--nextpnr-seed", default=0, help="Select nextpnr pseudo random seed")
    parser.add_argument("--nextpnr-placer", default="heap", choices=["sa", "heap"], help="Select nextpnr placer algorithm")
    parser.add_argument("--debug", action="store_true", help="Enable debug features. (UART has to be used with the wishbone-tool.)")
    parser.add_argument("--document-only", action="store_true", help="Do not build a soc. Only generate documentation.")
    parser.add_argument("--flash", action="store_true", help="Load bitstream")
    builder_args(parser)
    soc_core_args(parser)
    args = parser.parse_args()

    # Create the SOC
    soc = BaseSoC(cpu=args.cpu ,debug=args.debug, flash_offset=args.flash_offset, sys_clk_freq=int(args.sys_clk_freq), **soc_core_argdict(args))
    soc.set_yosys_nextpnr_settings(nextpnr_seed=args.nextpnr_seed, nextpnr_placer=args.nextpnr_placer)

    # Configure command line parameter defaults
    # Don't build software -- we don't include it since we just jump to SPI flash.
    builder_kwargs = builder_argdict(args)
    #builder_kwargs["compile_software"] = False

    if args.document_only:
        builder_kwargs["compile_gateware"] = False
    #if builder_kwargs["csr_svd"] is None:
    #    builder_kwargs["csr_svd"] = "../rust/icebesoc-pac/iCEBESOC.svd"
    #if builder_kwargs["memory_x"] is None:
    #    builder_kwargs["memory_x"] = "../rust/icebesoc-pac/memory.x"

    # Create and run the builder
    builder_kwargs["csr_csv"] = "build/csr.csv"
    builder = Builder(soc, **builder_kwargs)

    builder.build()
    lxsocdoc.generate_docs(soc, "build/documentation/", project_name="LoRaDongle SOC")

    # If requested load the resulting bitstream onto the LoRaDongle
    if args.flash:
        IceStormProgrammer().flash(0x00000000, path.join(builder.gateware_dir,"{}.bin".format(soc.build_name)))

if __name__ == "__main__":
    main()

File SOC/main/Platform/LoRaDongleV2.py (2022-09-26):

from litex.build.generic_platform import *
from litex.build.lattice import LatticePlatform
from litex.build.lattice.programmer import IceStormProgrammer


# IOs--------------------------------------------------------------------------------

_io = [
    # Clk
    ("clk", 0, Pins("46"), IOStandard("LVCMOS33")),
    #("cpu_reset", 0, Pins("21"), IOStandard("LVCMOS33")),

    ("btn", 0, Pins("21"), IOStandard("LVCMOS33")),     #Testing Input Button for interrupt!


    # Leds
    ("user_led", 0, Pins("37"),  IOStandard("LVCMOS33")),           #RX LED
    ("user_led", 1, Pins("36"),  IOStandard("LVCMOS33")),           #TX LED


    #### When changing config pins, make sure to change the firmware as well. sx126x_hal.c and Radio.c uses these pins to set up radio
    #LoRa Configuration Pins
    ("lora_config", 0, Pins("35"), IOStandard("LVCMOS33")),           #ANT_SW, Output
    ("lora_config", 1, Pins("31"), IOStandard("LVCMOS33")),           #RESET, Output

    #Dio Interrupt Pin
    ("dio1", 0, Pins("34"), IOStandard("LVCMOS33")),          #DIO1, Input


    #BusyPin
    ("lora_busy", 0, Pins("32"), IOStandard("LVCMOS33")),          #Busy, Input
    

    #UART
    ("serial", 0,
        Subsignal("tx", Pins("9")),
        Subsignal("rx", Pins("6")),
        IOStandard("LVCMOS33"),
    ),

    #SPIFlash
    ("spiflash", 0,
        Subsignal("cs_n", Pins("16"), IOStandard("LVCMOS33")),
        Subsignal("clk",  Pins("15"), IOStandard("LVCMOS33")),
        Subsignal("miso", Pins("17"), IOStandard("LVCMOS33")),
        Subsignal("mosi", Pins("14"), IOStandard("LVCMOS33")),
    ),


    #SPI
    ("spi_bus",0,                   
        Subsignal("clk", Pins("26")),                  
        Subsignal("cs_n", Pins("25")),                 
        Subsignal("mosi", Pins("27")),                 
        Subsignal("miso", Pins("28")),                 
        IOStandard("LVCMOS33"),
    ),


    #I2C
    ("i2c_bus",0,
        Subsignal("sda", Pins("18")),
        Subsignal("scl", Pins("19")),
        IOStandard("LVCMOS33")
    )

]



# Platform-----------------------------------------------------------------------------

class Platform(LatticePlatform):
	default_clk_name   = "clk"
	default_clk_period = 1e9/50e6

	def __init__(self, toolchain="icestorm"):
		LatticePlatform.__init__(self, "ice40-up5k-sg48", _io, toolchain=toolchain)

	def create_programmer(self):
        	return IceStormProgrammer()

	def do_finalize(self, fragment):
		LatticePlatform.do_finalize(self, fragment)
		self.add_period_constraint(self.lookup_request("clk", loose=True), 1e9/50e6)

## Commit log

2021-09-14 added regulators
    [LoRaDongle.sch, power_management.sch, sx1262_circuitry.sch]
2021-09-22 fpga power circuitry
    [fpga_configurarion.sch, fpga_power.sch]
2021-09-22 updated circuitry
    [LoRaDongle.sch, power_management.sch, sx1262_circuitry.sch]
2021-09-22 added sx1262 library part being used
    [LoRaDongle.kicad_pcb, LoRaDongle.sch, fpga_configurarion.sch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]
2021-09-30 adding usb interface
    [LoRaDongle.kicad_pcb, LoRaDongle.sch, bank_14_15.sch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]
2021-09-30 add eeprom
    [LoRaDongle.sch]
2021-10-01 ft232h completed
    [LoRaDongle.kicad_pcb, LoRaDongle.sch, USB_Interface.sch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]
2021-10-04 added flash memory configuration
    [LoRaDongle.sch, USB_Interface.sch, bank_14_15.sch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]
2021-10-07 updated RF circuitry
    [LoRaDongle.sch, USB_Interface.sch, bank_14_15.sch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]
2021-10-13 updated with dip switch
    [LoRaDongle.sch, USB_Interface.sch, bank_14_15.sch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]
2021-11-23 Lattice fork
    [LoRaDongle_Xilinx.kicad_pcb, LoRaDongle_Xilinx.sch, LoRaDongle_iCE40.kicad_pcb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]
2021-11-23 renaming Xilinx folder
    [LoRaDongle.kicad_pcb, LoRaDongle.sch, USB_Interface.sch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]
2021-12-08 initial changes to iCE40UP5k
    [LoRaDongle_iCE40.sch, USB_Interface.sch, ice40hx4k_circuit.sch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]
2021-12-10 changed to sx1261
    [LoRaDongle_iCE40.sch, USB_Interface.sch, ice40hx4k_circuit.sch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]
2021-12-12 connected FPGA to SX1261
    [LoRaDongle_iCE40.sch, ice40up5k_circuit.sch]
2021-12-14 added footprints
    [LoRaDongle_iCE40.sch, USB_Interface.sch, ice40up5k_circuit.sch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]
2021-12-20 PCB Layout V01
    [LoRaDongle_iCE40.kicad_pcb, LoRaDongle_iCE40.sch, USB_Interface.sch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]
2021-12-27 first traces laid
    [LoRaDongle_iCE40.kicad_pcb]
2022-01-01 added more traces
    [LoRaDongle_iCE40.kicad_pcb, sx1261_circuitry.sch]
2022-01-03 breakout of bga part
    [LoRaDongle_iCE40.kicad_pcb, LoRaDongle_iCE40.sch, sx1261_circuitry.sch]
2022-01-04 added to other traces
    [LoRaDongle_iCE40.kicad_pcb, LoRaDongle_iCE40.kicad_sch, USB_Interface.kicad_sch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]
2022-01-07 added copper pours
    [LoRaDongle_iCE40.kicad_pcb, LoRaDongle_iCE40.kicad_sch, USB_Interface.kicad_sch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]
2022-01-10 updating unconnected traces
    [LoRaDongle_iCE40.kicad_pcb, LoRaDongle_iCE40.kicad_sch, USB_Interface.kicad_sch]
2022-01-11 updating symbol details
    [LoRaDongle_iCE40.kicad_pcb, LoRaDongle_iCE40.kicad_sch, USB_Interface.kicad_sch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]
2022-01-17 updated BOM
    [LoRaDongle_iCE40.kicad_pcb, LoRaDongle_iCE40.kicad_sch, USB_Interface.kicad_sch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]
2022-01-18 switched relative libraries
    [LoRaDongle_iCE40.kicad_pcb]
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2022-01-18 generate raw bom csv from kicad
    [LoRaDongle_iCE40.csv, LoRaDongle_iCE40.kicad_sch, USB_Interface.kicad_sch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]
2022-01-19 update vias and text on schematic
    [LoRaDongle_iCE40.kicad_pcb, ice40up5k_circuit.kicad_sch]
2022-01-27 added usb flash testpoints & jumper for fpga oscillator
    [LoRaDongle_iCE40.kicad_pcb, LoRaDongle_iCE40.kicad_sch, USB_Interface.kicad_sch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]
2022-02-04 updating silkscreen
    [LoRaDongle_iCE40.kicad_pcb, LoRaDongle_iCE40.kicad_sch, USB_Interface.kicad_sch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]
2022-02-06 completed silkscreen
    [LoRaDongle_iCE40.csv, LoRaDongle_iCE40.kicad_pcb, ice40up5k_circuit.kicad_sch]
2022-02-07 gerbers and centroid file added
    [LoRaDongle_iCE40-B_Cu.gbl, LoRaDongle_iCE40-B_Mask.gbs, LoRaDongle_iCE40-B_Paste.gbp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]
2022-02-15 updating text in schematic
    [LoRaDongle_iCE40.kicad_sch, USB_Interface.kicad_sch, ice40up5k_circuit.kicad_sch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]
2022-03-08 updated submodules for xilinx
    [LoRaDongle_iCE40.kicad_pcb]
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2022-05-12 pcb files in pcb directory
    [LoRaDongle_Xilinx.kicad_pcb, LoRaDongle_Xilinx.sch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]
2022-05-12 added soc directory and files for arty test
    [csr.csv]
2022-05-18 added timers
    [csr.csv]
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2022-05-25 minor soc update - order of pads for SPIMaster
    [csr.csv]
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2022-05-26 tested delays between register writes of SPI
    [csr.csv]
2022-05-27 sending byte on spi
    [csr.csv]
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2022-06-03 updated SoC, tested firmware, not working
    [LoRaDongle.py, main.c]
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2022-06-28 separated nexys and arty files
    [csr.csv]
2022-07-15 updated ftdi and flash chip, removed xilinx project
    [LoRaDongle_Xilinx.kicad_pcb, LoRaDongle_Xilinx.sch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]
2022-07-18 updated jumpers, connectors and testpoints
    [LoRaDongle_iCE40.kicad_sch, USB_Interface.kicad_sch, ice40up5k_circuit.kicad_sch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]
2022-07-20 updated layout and routing
    [LoRaDongle_iCE40.kicad_pcb, LoRaDongle_iCE40.kicad_sch, USB_Interface.kicad_sch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]
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2022-07-22 updated schematic to QFN ice40
    [LoRaDongle_iCE40.kicad_pcb, LoRaDongle_iCE40.kicad_sch, ice40up5k_circuit.kicad_sch]
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2022-08-09 removing nexys directory from main
    [csr.csv]
2022-08-09 removed arty_test from main
    [csr.csv]
2022-08-15 ignored/deleted redundant PCB files
    [bank_14_15.sch, fpga_configurarion.sch, fpga_power.sch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]
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2022-11-23 updated testing firmware so doesn't hang when a packet is receied incorrectly
    [main.c]
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2022-12-03 done structured latency testing
    [Test_1.csv, Test_2.csv, Test_3.csv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]
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2022-12-11 line of sight testing done
    [Test_1.csv, Test_2.csv, Test_3.csv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]
2022-12-13 redid some outdoor tests
    [Test_1.csv, Test_2.csv, Test_3.csv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]
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2023-01-10 added some more testing
    [Test_10.csv, Test_11.csv, Test_12.csv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]
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2023-01-21 updated cbd tests, analyser notebook
    [Test_5.csv, Test_6.csv, tests_info.csv]
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
